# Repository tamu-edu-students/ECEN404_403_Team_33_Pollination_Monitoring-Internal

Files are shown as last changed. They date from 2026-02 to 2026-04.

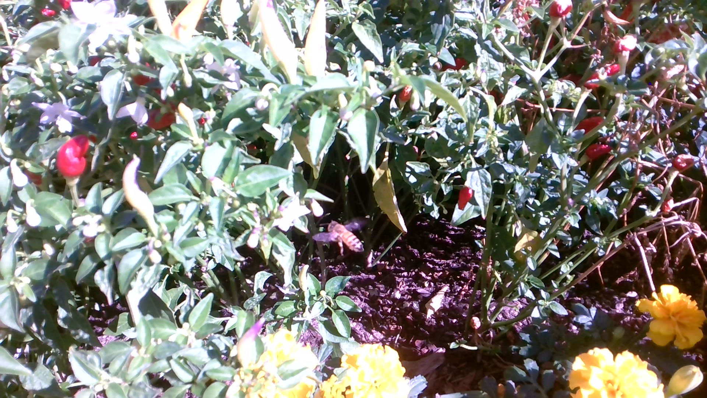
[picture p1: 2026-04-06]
pi_program/sample0.jpg

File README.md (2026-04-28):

# ECEN 404 / ECEN 403 — Team 33 Pollination Monitoring System (AgriPollinate)

## Overview

AgriPollinate is a smart pollination monitoring system designed to help farmers track pollinator activity in real time. Traditional monitoring methods are manual, slow, and not scalable. This system automates the process using LiDAR sensing, image-based machine learning, and live dashboard visualization.

The system detects when insects interact with flowers, classifies them as pollinators or non-pollinators, and displays results through a live dashboard with heatmap visualization.

---

## System Architecture

The system is composed of multiple integrated subsystems working together in an end-to-end pipeline from detection to visualization:

| Subsystem | Folder | Description |
|---|---|---|
| LiDAR Processing & ML | `lidar_ML/` | Motion detection, feature extraction, Random Forest classification |
| Image Classification | `image_ML/` | YOLOv8-based insect detection via FastAPI backend |
| Raspberry Pi Control | `pi_program/` | Hardware coordination and event pipeline triggering |
| LiDAR Client | `lidar_client_communication/` | LiDAR data streaming and event generation |
| Communication Layer | `communication_protocol.py` | Structured packet-based messaging between subsystems |
| Web Dashboard | `agripollinate_webpage/` | Real-time detection results and heatmap visualization |
| Power / Hardware | `board_v1_files/`, `board_v2_file/` | Custom PCB designs for solar power management |
| Enclosure | `enclosing_v1_stl/` | 3D-printed housing structure |

---

## Data Flow

```
LiDAR detects motion near flower
          ↓
Event generated with flower ID + timestamp
          ↓
Camera captures corresponding image
          ↓
Image ML model classifies insect (YOLOv8)
          ↓
LiDAR ML model validates classification (Random Forest)
          ↓
Sensor fusion merges both results
          ↓
Data sent to dashboard via TCP communication layer
          ↓
Heatmap updated in real time
```

---

## Key Features

- Real-time pollinator detection at the flower level
- LiDAR-based motion analysis with ML classification
- YOLOv8 image-based insect detection
- Random Forest LiDAR model with ~92% cross-validation F1 score
- Sensor fusion between camera and LiDAR subsystems
- TCP-based structured packet communication
- Live heatmap dashboard visualization
- Custom dataset collected from real hardware deployment
- Batch data collection pipeline for model retraining

---

## Machine Learning Components

### LiDAR Model (`lidar_ML/`)
- **Algorithm:** Random Forest classifier
- **Input:** Feature vectors extracted from LiDAR scan sequences
- **Output:** `pollinator` / `non-pollinator` + confidence score
- **Performance:** ~92% cross-validation F1 score

### Image Model (`image_ML/`)
- **Algorithm:** YOLOv8 object detection
- **Input:** Camera frames triggered by LiDAR events
- **Output:** Bounding box + insect class label
- **Backend:** FastAPI inference server

---

## Dataset

Both ML models use custom datasets collected from real hardware tests in the deployment environment:

- Bees
- Butterflies
- Ladybugs
- Beetles
- Grasshoppers
- Environmental noise / non-insect motion

LiDAR event data is stored in `lidar_ML/dataset/`. Image data is managed within `image_ML/`.

---

## Hardware

- Raspberry Pi 5
- LiDAR sensor module
- Camera module
- Custom PCB (v1 and v2 designs)
- Solar power management system
- 3D-printed enclosure housing

---

## Communication Protocol

All subsystems communicate using a structured packet format defined in [`communication_protocol.py`](communication_protocol.py). Key packet types include:

- `PACKET_ID_LIDAR_OUTGOING` — LiDAR event data from the sensor
- `PACKET_ID_IMAGE_RESPONSE` — Image classification result from the camera subsystem
- `PACKET_ID_LIDAR_RESPONSE` — LiDAR ML classification result

---

## Folder Structure

```
ECEN404_403_Team_33_Pollination_Monitoring-Internal/
│
├── lidar_ML/                      # LiDAR ML subsystem (see lidar_ML/README.md)
├── image_ML/                      # Image-based ML detection subsystem
├── lidar_client_communication/    # LiDAR data streaming client
├── pi_program/                    # Raspberry Pi hardware control
├── communication_protocol.py      # Shared packet communication layer
├── agripollinate_webpage/         # Web dashboard frontend
│
├── board_v1_files/                # PCB v1 design files
├── board_v2_file/                 # PCB v2 design files
├── enclosing_v1_stl/              # 3D enclosure STL files
│
├── 403_presentations/             # ECEN 403 presentation materials
├── presentations_404/             # ECEN 404 presentation materials
│
└── README.md                      # This file
```

---

## System Improvements (ECEN 403 → ECEN 404)

- Switched from rule-based scan logic to ML-based LiDAR classification
- Replaced cloud communication with TCP-based local system
- Improved dataset quality and removed duplicate/noisy samples
- Added sensor fusion between LiDAR and camera subsystems
- Improved real-time synchronization between subsystems
- Introduced structured packet communication protocol
- Built full end-to-end automated detection pipeline

---

## Results

- ~92% pollinator classification accuracy on held-out test set
- Reliable real-time detection pipeline with low latency
- Stable sensor fusion logic across LiDAR and camera
- Successful full system integration and deployment testing

---

## Future Improvements

- Add long-term database storage for historical activity tracking
- Improve model performance on edge cases and rare insect types
- Expand dataset with more environmental and lighting variations
- Optimize real-time inference speed for embedded deployment
- Improve dashboard analytics and user-facing reporting
- Deploy cloud backup system for data redundancy

---

## Team

ECEN 403 / ECEN 404 — Team 33
SICKSense PathFinder AgriPollinate
- [`Paavan Bagla`](https://github.com/PaavanBagla)
- [`Josiah Faircloth`](https://github.com/Josiahtate-tamu)
- [`Jason Agnew`](https://github.com/oops23)
- [`Samuel Ramos`](https://github.com/samwr-1)

Texas A&M University

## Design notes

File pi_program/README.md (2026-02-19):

# SICKSense Agripollinate Pi Program

This folder contains the Raspberry Pi master-side runtime for flower-visit event detection, image capture, and bidirectional packet routing between image and LiDAR clients.

## Updated Program Structure

The architecture has been refactored from the earlier object-tracking layout into an event-driven, flower-centric pipeline:

1. LiDAR stream is read in real time.
2. Flower occupancy is detected with per-flower thresholds and confirmation windows.
3. Event start triggers image burst capture/transmission.
4. Event end packages visit data for LiDAR data client transmission.
5. Master forwards response packets between image and LiDAR clients using a shared protocol.

## Files

### Core Runtime Modules

- **`master_main.py`**
     - Main orchestrator for all subsystems.
     - Handles startup/shutdown, watchdog checks, testing mode, event callbacks, and cross-server linking.

- **`lidar_parser.py`**
     - Manages TCP connection to the SICK LiDAR scanner.
     - Parses `LMDscandata` telegrams.
     - Supports selective index parsing so only required flower angle indices are decoded for detection.

- **`event_detector.py`**
     - Performs flower visit detection from scan data.
     - Uses configured flower angle indices + background distances.
     - Emits `start` and `end` events with distance history and metadata.

- **`image_capture.py`**
     - Runs image server socket and captures images via `fswebcam`.
     - Sends image data with packet headers (`1050`) and receives image-client responses (`2050`).
     - Forwards responses to the LiDAR data server when connected.

- **`lidar_data_server.py`**
     - Runs LiDAR data server socket for event payload delivery.
     - Sends event packets (`1025`) and handles LiDAR-client responses (`2025`).
     - Forwards responses to the image server when connected.

- **`communication_protocol.py`**
     - Defines packet header/payload format, serialization, and parsing.
     - Defines packet IDs used by both server paths (`1025`, `1050`, `2025`, `2050`).
     - Provides shared event ID helpers.

### Setup / Utility Module

- **`flower_setup.py`**
     - One-time/setup tool to build flower configuration from baseline scans.
     - Produces flower angle indices and background distances for use by the event detector.

### Data Directories

- **`image_downloads/`** - local image output/download area.
- **`lidar_downloads/`** - local LiDAR/event data output/download area.

## High-Level Data Flow

```text
LiDAR Scanner
          -> lidar_parser
          -> event_detector
                -> on start: image_capture (send 1050 packets)
                -> on end:   lidar_data_server (send 1025 packets)

Image client response (2050)
          -> image_capture
          -> forwarded to lidar_data_server / LiDAR client

LiDAR client response (2025)
          -> lidar_data_server
          -> forwarded to image_capture / Image client
```

## Key Configuration (master_main.py)

- **LiDAR Connection**: `LIDAR_HOST`, `LIDAR_PORT`
- **Image Server**: `IMAGE_SERVER_HOST`, `IMAGE_SERVER_PORT`, `IMAGE_SAVE_DIR`, `IMAGE_RESOLUTION`, `BURST_SIZE`
- **LiDAR Data Server**: `LIDAR_DATA_HOST`, `LIDAR_DATA_PORT`, `LIDAR_DATA_SAVE_DIR`
- **Event Detection**: `EVENT_DIST_THRESHOLD`, `EVENT_START_CONFIRM_SCANS`, `EVENT_END_CONFIRM_SCANS`
- **Reliability**: `WATCHDOG_TIMEOUT`, `CONNECTION_TIMEOUT`

## Running

On Raspberry Pi (master):

```bash
cd pi_program
python3 master_main.py
```

## Dependencies

Python standard library only for core runtime modules.

System dependency for image capture:

- `fswebcam` (example install on Debian/Raspberry Pi OS):

```bash
sudo apt-get install fswebcam
```

## Change Summary vs Previous Structure

- Replaced legacy object-tracking-centric flow with flower visit event detection.
- Added/standardized packet-based cross-client protocol support through `communication_protocol.py`.
- Added dedicated LiDAR data server path via `lidar_data_server.py`.
- Added setup utility `flower_setup.py` for deriving flower index/background configuration.
- Updated LiDAR parse path to support selective index decoding for lower per-scan processing load.

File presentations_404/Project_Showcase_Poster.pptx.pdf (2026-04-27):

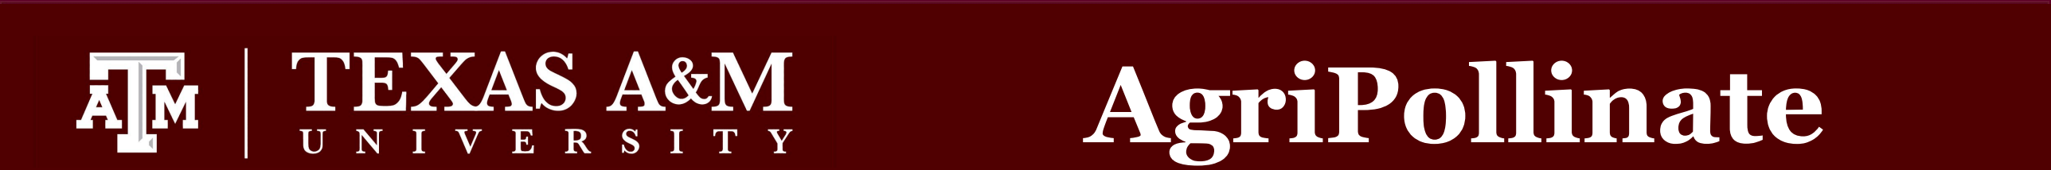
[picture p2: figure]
AgriPollinate

## Engineering Analysis

Throughout the course, our project changed in many ways, our scope, data collection methods, and power had to be refined to match our goals. System validation was performed across hardware and software subsystems. Detection accuracy was verified within a set detection range under field conditions. The ML classification models were trained and evaluated on labeled pollinator image datasets. Finally, the PCB power charging rate was validated with and without system load.

6cm

Problem Definition

Farmers lack an efficient and scalable way to monitor pollination, relying on manual and inconsistent methods.

AgriPollinate uses LiDAR and image based detection to automatically track and classify pollinator activity, displaying results through heatmaps on a dashboard.

The portable, solar powered system enables real time field deployment and improved decision making.

Methodology

- Setup: Flowers are configured with GPS coordinates in the system and dual TCP connections are established while the devices are powered by a PCB.
- Detection: The LiDAR continuously scans flowers for movement activity.
- Event Trigger: When movement is detected across 6 consecutive scans, an event is triggered and the camera captures an image of the flower.
- Classification: LiDAR data is sent to the ML model; camera image is sent for visual classification. Both are processed simultaneously.
- Dashboard: Displays LiDAR heatmap, insect species counts, top 3 pollinators, insect visits per each hour of the day, and triggers pest alerts.

## Outcomes

HERE PUT THE OUTCOMES, CONSOLE OUTPUT? GRAPHS AND CHARTS?

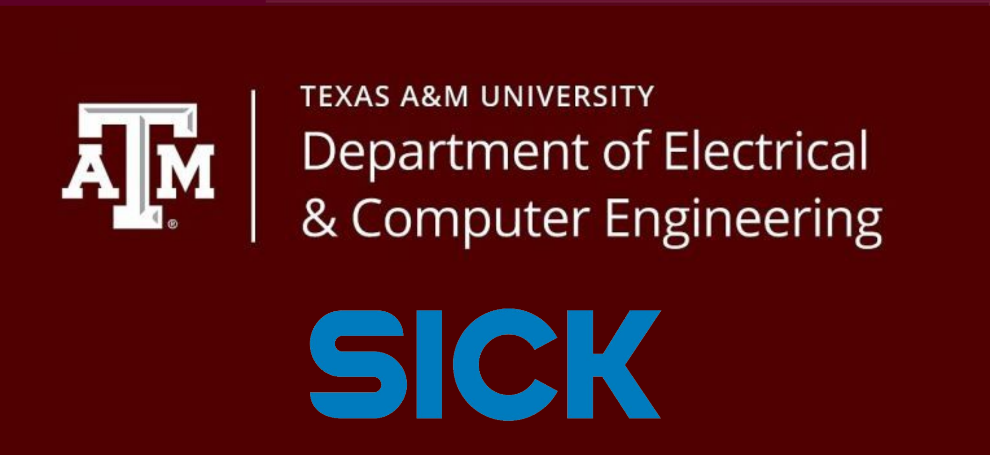
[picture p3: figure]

## Impact

Our project serves as a proof of concept model for a pollination monitoring system which can provide farmers with real-time pollination data to make faster, more informed decisions and reduce reliance on manual monitoring, cutting labor costs and human error. Heat-map visualization enables spatial analysis of pollinator hotspots across fields which can inform hive placement adjustments and solar-powered portability makes deployment viable for small and large-scale farms alike.

## References

- https://www.sciencedirect.com/science/article/pii/S2214574525000379 (https://www.sciencedirect.com/science/article/pii/S2214574525000379)

## Acknowledgments

The team would like to thank SICK for their generous sponsorship and providing the TiM551 LiDAR.

Special thanks to Faculty Advisor Prof. Stavros Kalafatis, Dr. John Lusher, and TA Roman Vengas for their guidance.

### Jason Agnew | Paavan Bagla | Josiah Faircloth | Samuel Ramos

Sponsor: SICK | Faculty: Stavros Kalafatis

Performance Metrics for Rasp. Pi

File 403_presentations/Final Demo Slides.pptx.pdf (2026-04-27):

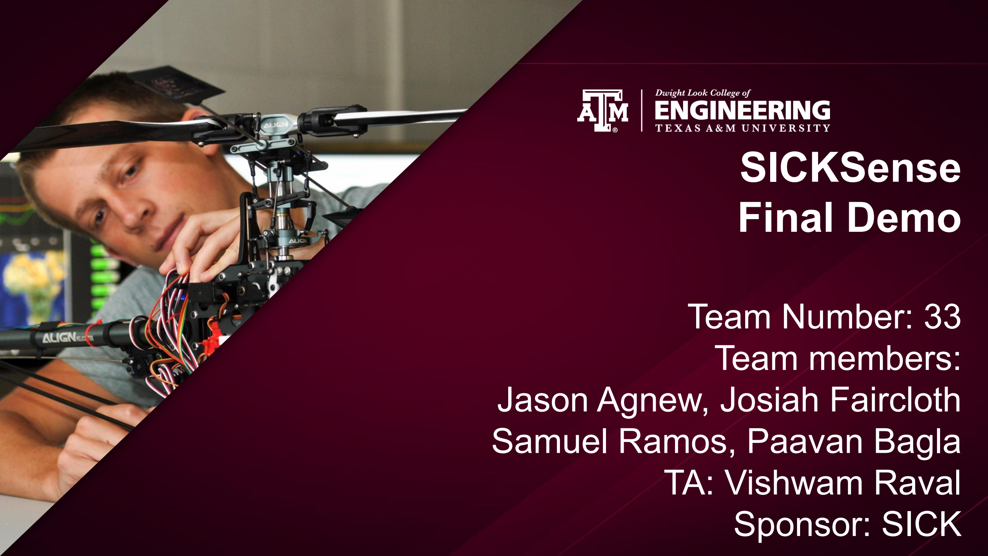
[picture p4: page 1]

# SICKSense Final Demo

## Team Number: 33 Team members: Jason Agnew, Josiah Faircloth Samuel Ramos, Paavan Bagla TA: Vishwam Raval Sponsor: SICK

# Project Summary

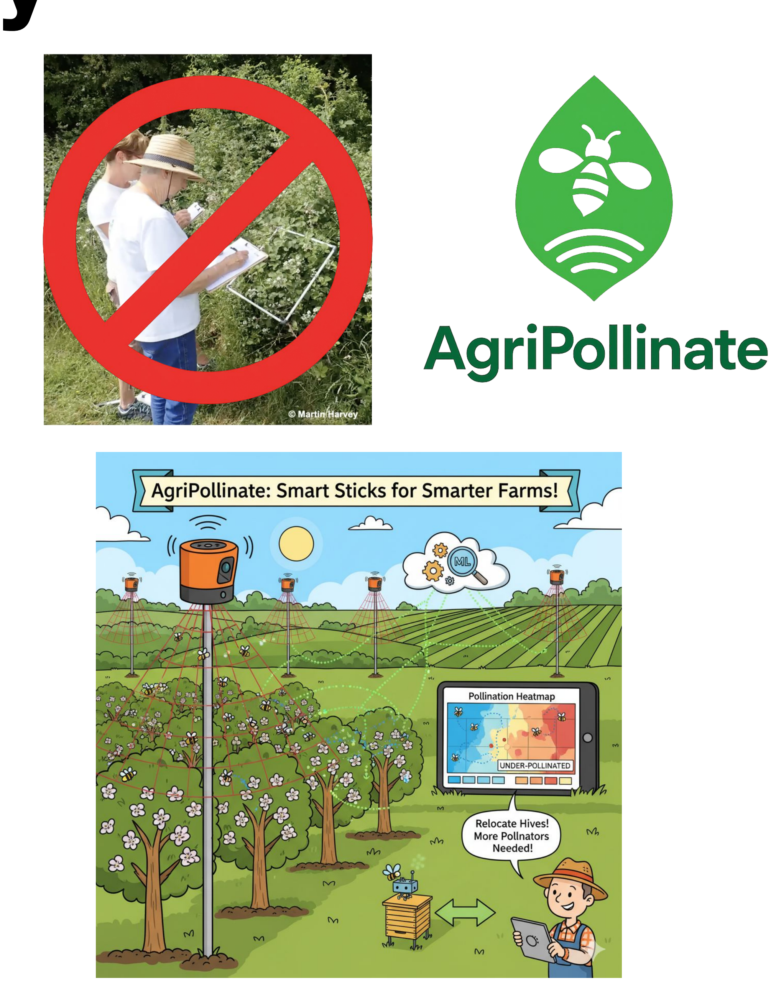
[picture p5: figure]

Problem statement:
- Farmers lack reliable, real-time insights into pollination activity. Existing methods are reactive, labor-intensive, and often inaccurate, leading to missed pollination deficits that directly reduce crop yield and quality.

Our Solution:
- AgriPollinate is a Light Detection and Ranging (LiDAR)-powered monitoring system that continuously tracks pollinator activity and generates easy-to-read heatmaps.
- Farmers can access these heatmaps through a simple dashboard, allowing them to quickly identify under-pollinated areas, optimize hive placement, and improve crop yield and quality.

# System Overview

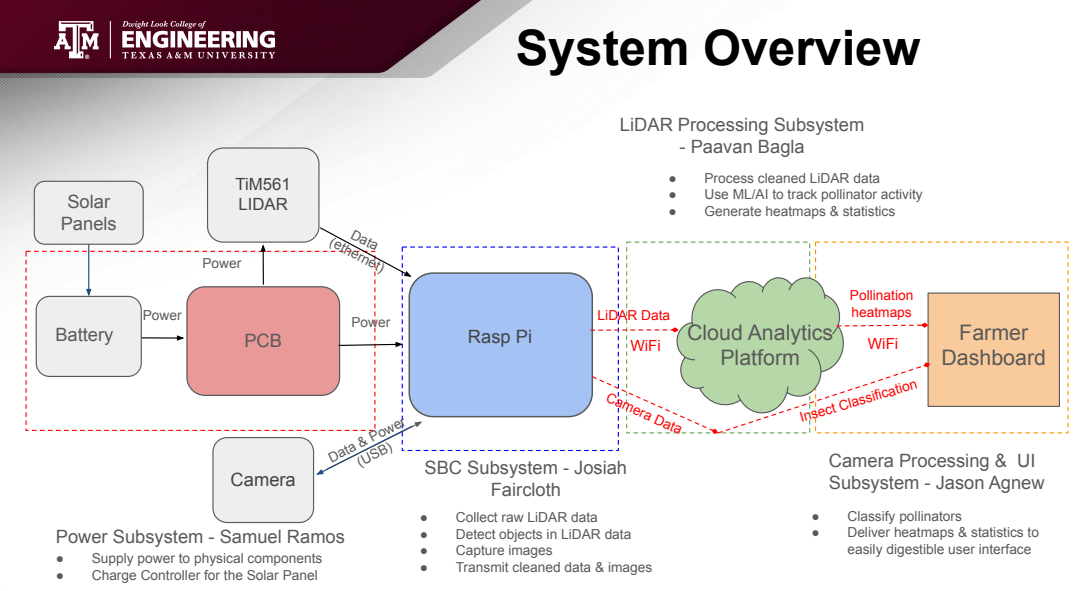
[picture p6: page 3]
Power; Data (ethernet); Pollination heatmaps; Insect Classification; PCB; TiM561 LIDAR; Rasp Pi; Camera; Cloud Analytics Platform; Farmer Dashboard; Battery; Data & Power; (USB); Faircloth; - Paavan Bagla; LiDAR Data; Camera Data; WiFi; Solar Panels

LiDAR Processing Subsystem

● Process cleaned LiDAR data
● Use ML/AI to track pollinator activity
● Generate heatmaps & statistics

Camera Processing & UI
Subsystem - Jason Agnew

SBC Subsystem - Josiah

● Collect raw LiDAR data
● Detect objects in LiDAR data
● Capture images
● Transmit cleaned data & images

● Classify pollinators
● Deliver heatmaps & statistics to
easily digestible user interface

Power Subsystem - Samuel Ramos
● Supply power to physical components
● Charge Controller for the Solar Panel

# Single Board Computer (SBC) Subsystem

Josiah Faircloth

Designed:
- Image capture & transmission program
– Captures images via camera attached to Raspberry Pi and transmits using TCP
- LiDAR data collection program
– Connects to TiM561 using TCP, receives scan data, and writes to a file
- LiDAR data object detection algorithm
– Reads scan data file, groups data points into objects, and triggers when a new object is detected
- Integrated program unifying all previous modules including a watchdog timer.

Tested:
- TCP/SSH connections with raspberry pi
- Image capture & transmission latency
- TiM561 connection & data parsing
- Object detection algorithm accuracy

# SBC Subsystem

Josiah Faircloth

Validation:
- >1 hr stable connection between pi and device on same network
- First Image ~1ms after trigger, average latency between pictures is ≤ 200ms
- >1 hr successful connection & data parsing with LiDAR
- Roughly 8/10 successful detection with simulated insect
- Roughly 3/10 detection triggers are false positives

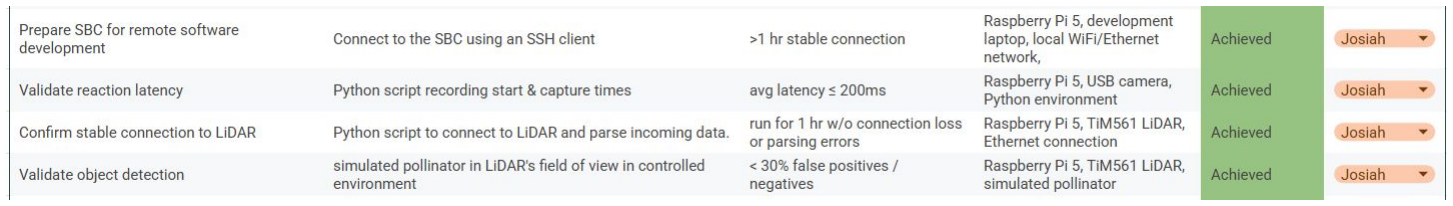
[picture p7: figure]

# SBC Subsystem

Josiah Faircloth

404 Tasks:
- Integrate TCP server/client with LiDAR & camera processing subsystems
- Optimize algorithm for performance and memory use to reduce strain on Raspberry Pi
- Continued testing and optimization of object detection algorithm
- Implement memory management system for pi
- Field testing over extended periods with real bees

## LiDAR Data Processing & Pollination Heatmaps System:

### Subsystem Summary — Paavan Bagla

Goal:
- Detect, identify, and visualize bee activity using LiDAR data to generate pollination heatmaps that inform autonomous robot behavior.

Design & Implementation:
- Integrated RViz + Gazebo simulation environment for sensor and visualization testing
- Built ROS2 pipeline for LiDAR /scan ingestion, bee point extraction, clustering, and heatmap generation
- Implemented both real-time and cumulative heatmap logic for visualizing bee activity

## LiDAR Data Processing & Pollination Heatmaps System:

### System Design (Algorithms Used) — Paavan Bagla

- Polar-to-Cartesian Conversion & Filtering: Transforms LiDAR (angle, range) pairs into 2D (x, y) coordinates and removes invalid or noisy readings.
- DBSCAN clustering: Uses density-based clustering to group nearby LiDAR points, helping distinguish actual bee detections from random noise.
- Gaussian smoothing: Applies Gaussian filtering using SciPy (or fallback) to smooth the heatmap grid and highlight consistent regions of bee activity.
- Heatmap accumulation logic: Updates two maps:
– | Real-time heatmap → live detections per frame
– | Cumulative heatmap → tracks total pollinating bee activity and count over time.
- ROS2 integration for real-time data streaming: Subscribes to /scan, processes detections, and publishes heatmaps to RViz.

## LiDAR Data Processing & Pollination Heatmaps System:

## Simulated LiDAR Detection in Gazebo & RViz

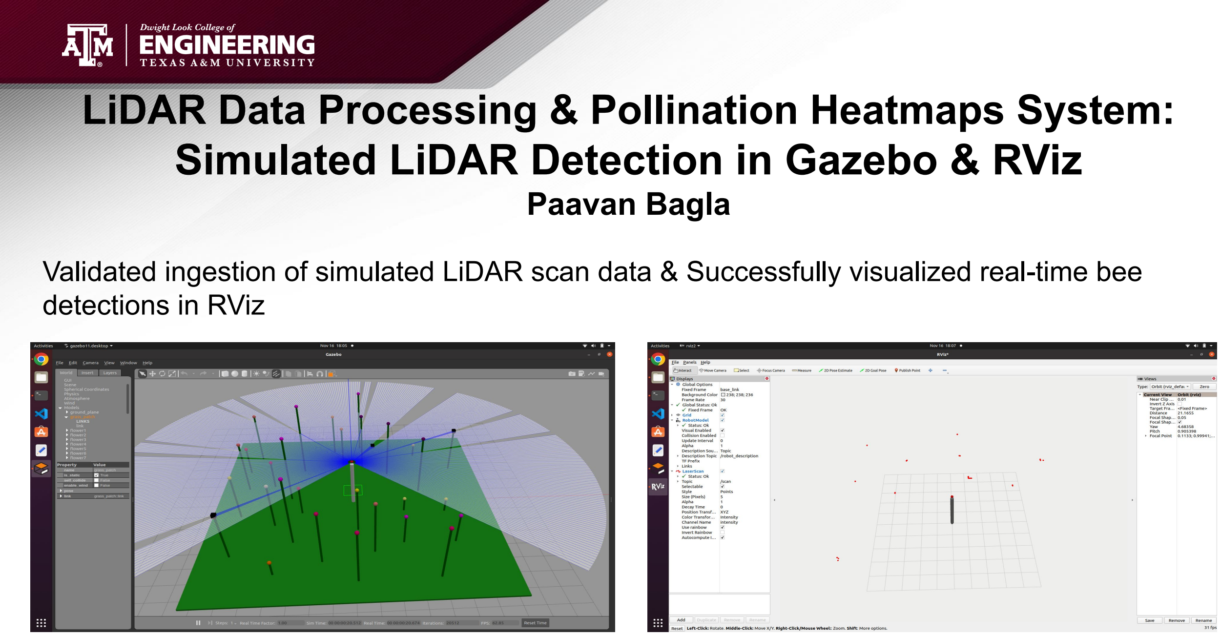
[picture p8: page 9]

### Paavan Bagla

Validated ingestion of simulated LiDAR scan data & Successfully visualized real-time bee detections in RViz

## LiDAR Data Processing & Pollination Heatmaps System:

### Validation Plan — Paavan Bagla

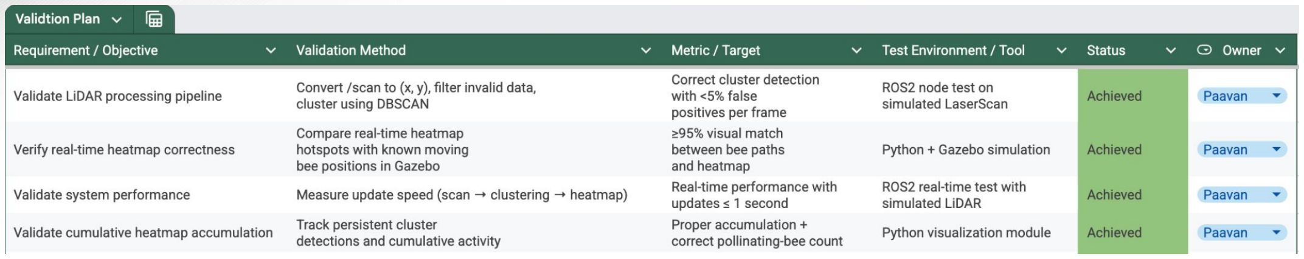
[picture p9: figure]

Testing & Validation:
- Verified LiDAR scan processing and visualization in RViz
- Tested with simulated bees in custom Gazebo environment
- Heatmaps reliably highlight real-time and cumulative pollination activity
- Counting + clustering algorithms run consistently in real time

## 404 Tasks: LiDAR & Heatmap Subsystem

### Paavan Bagla

- Machine Learning Integration
– Train a model to classify LiDAR points as bees vs. non-bees – Detect if a bee is pollinating
– Integrate ML predictions into the existing real-time pipeline
- Enhanced Heatmap Visualization
– Enhance real-time and cumulative heatmap visuals for better user experience
- Testing & Validation
– Test ML-enabled subsystem with larger simulated swarms
– Validate real-time performance with multiple moving bees
– Confirm correct pollinator counts and heatmap hotspot accuracy
- System Integration
– Use actual SICK TiM561 2D LiDAR data instead of simulated scans
– Integrate with other subsystems and finally display heatmaps and pollination analytics on the UI dashboard

# Camera Processing & UI Subsystem

Jason Agnew

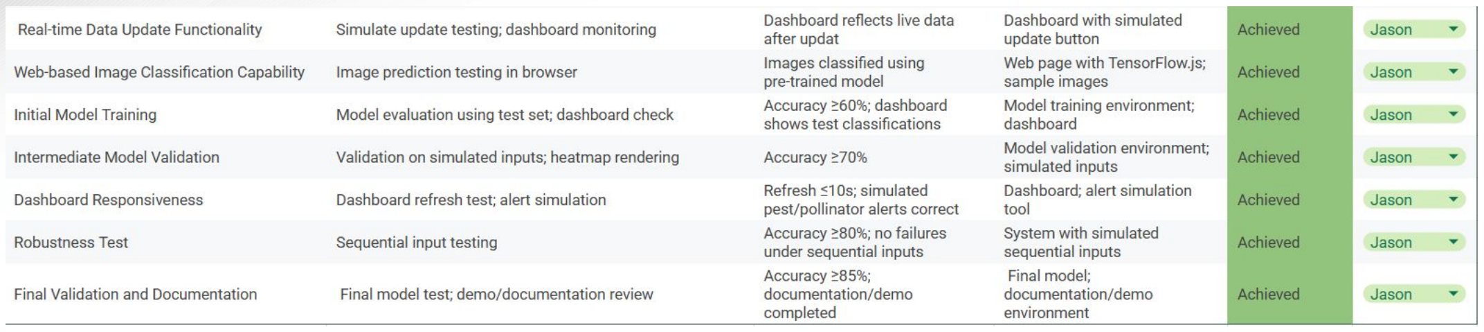
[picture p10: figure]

# Species

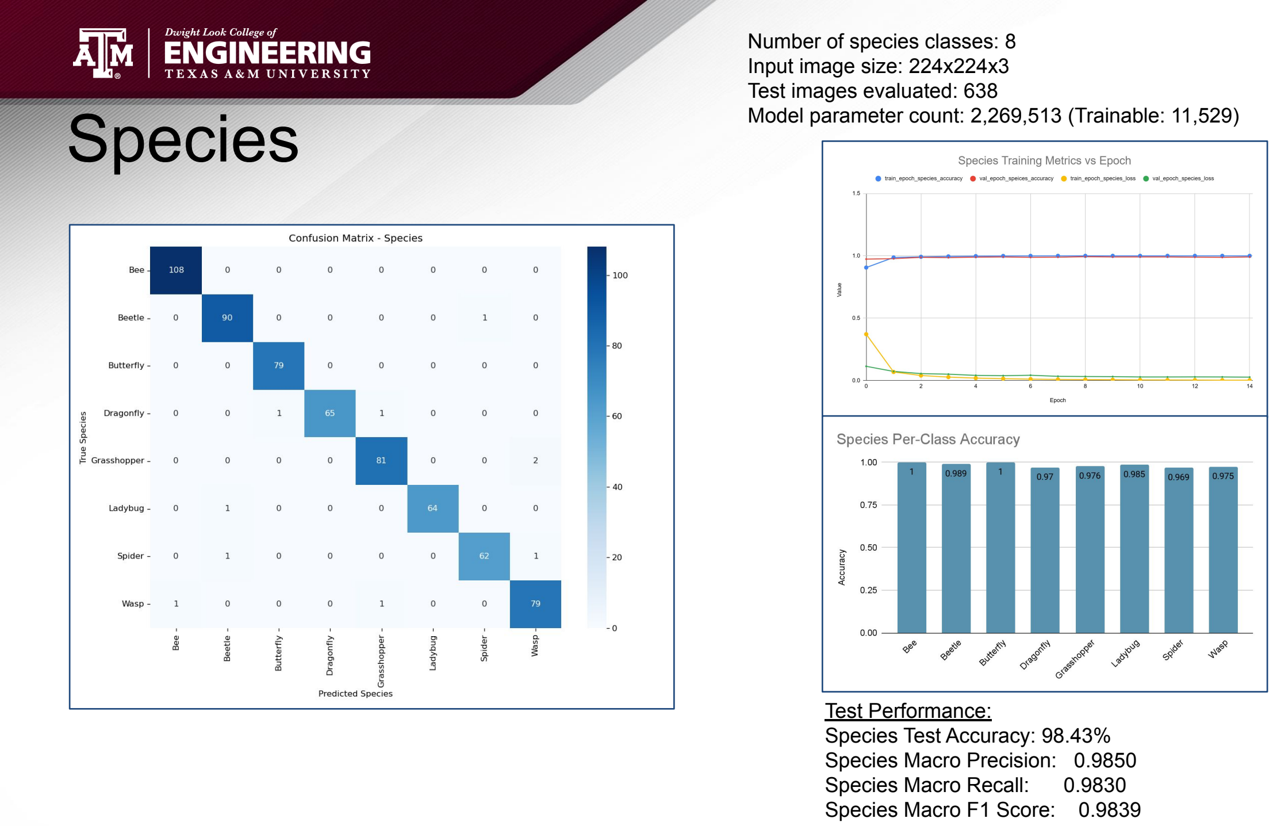
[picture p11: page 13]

Number of species classes: 8
Input image size: 224x224x3
Test images evaluated: 638
Model parameter count: 2,269,513 (Trainable: 11,529)

Test Performance:
Species Test Accuracy: 98.43% Species Macro Precision: 0.9850 Species Macro Recall: 0.9830 Species Macro F1 Score: 0.9839

Pollinator/Pest confusion matrix: [[316 3]
[ 8 311]]

# Roles

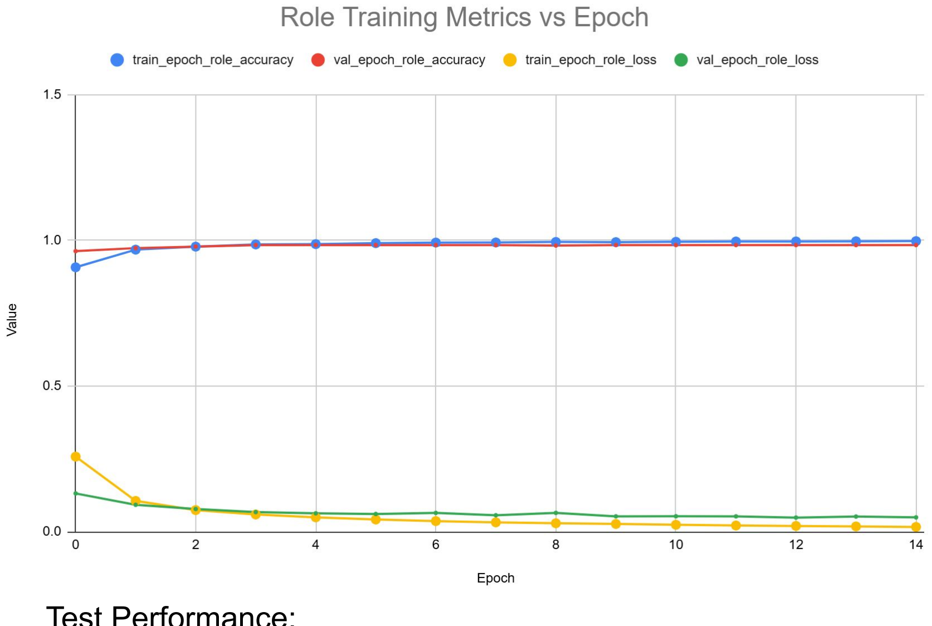
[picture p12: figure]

Test Performance:
Role Test Accuracy: 98.28% Role Precision: 0.9904
Role Recall: 0.9749
Role F1 Score: 0.9826

# Solar Power Management Circuit

### Samuel Ramos

403 Accomplishments Summary:
- Schematics for Step-down converter & Charge Controller has been design, passed the validation check and have been completed
- Learned a new software, Altium, in order to complete the schematics and more importantly the design of the PCB, which combines the two schematics
- PCB design has arrived and been validated to match the design in Altium

# Solar Power Management Circuit

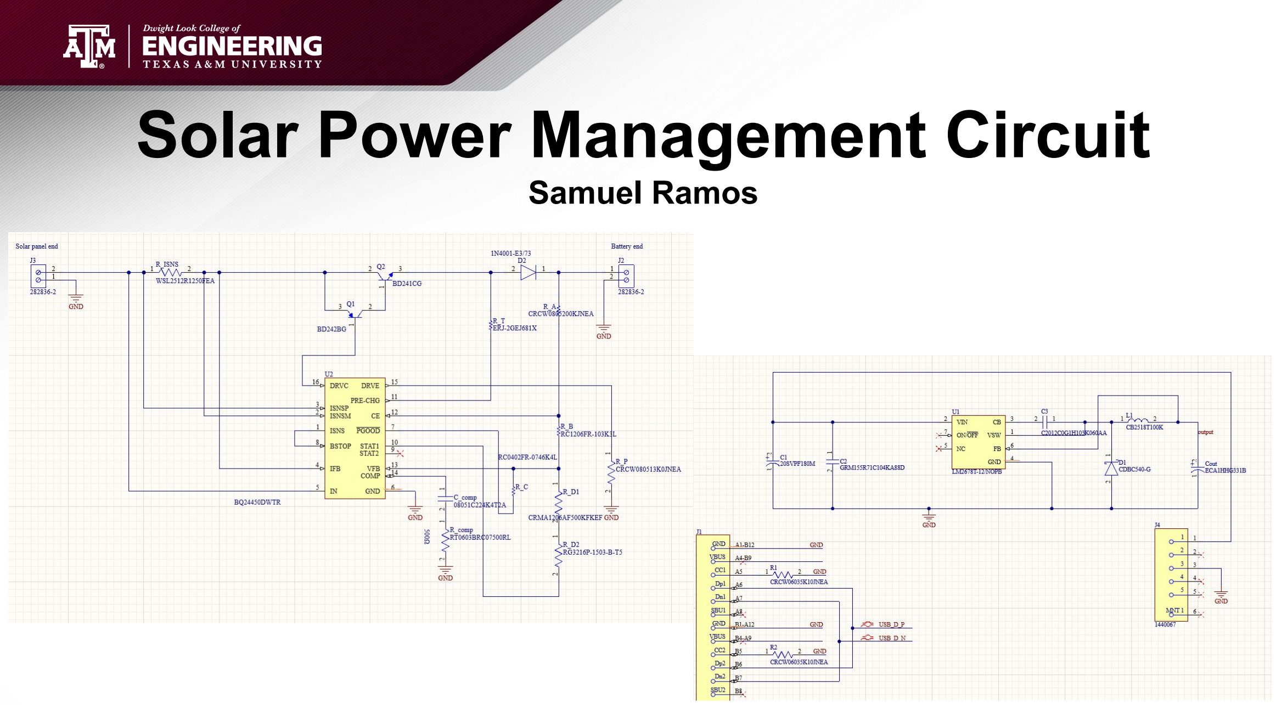
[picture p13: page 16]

### Samuel Ramos

# Solar Power Management Circuit

### Samuel Ramos

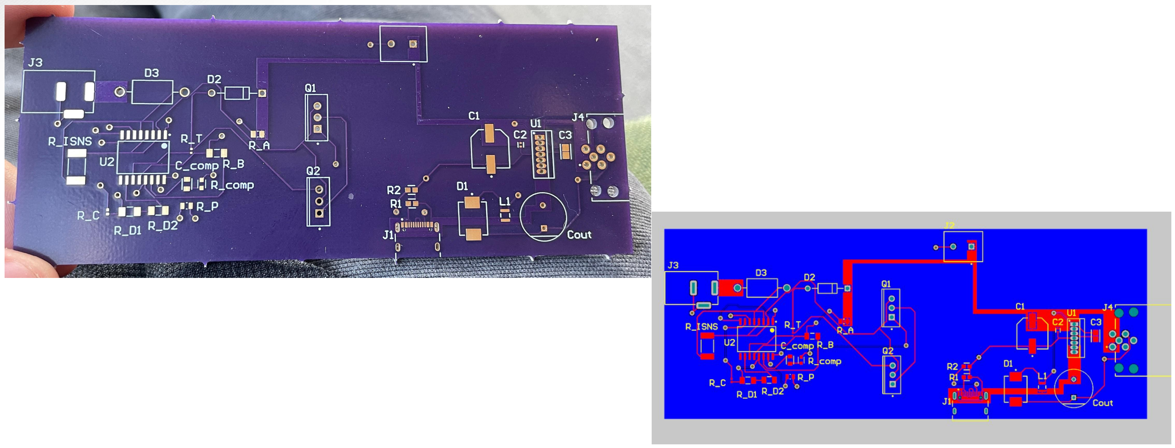
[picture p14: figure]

# Solar Power Management Circuit

### Samuel Ramos

Remaining Tasks:
- Soldering of parts onto PCB
- Testing of completed PCB (Power, I/O)
- Validation of testing compared to plan
Key Design activity to be completed in 404:
- Possible Redesign of Schematics and therefore PCB based on results of testing
- Enclose for PCB and components

## Remaining Tasks: Camera Processing & UI Subsystem

## Jason Agnew

Remaining Tasks Before Demo:
- Complete bounding-box annotations for the training dataset to finalize the labeled image set.
- Begin training the prebuilt MobileNet model using the fully annotated dataset.
- Evaluate model performance first using images from the dataset, then testing with images captured from the actual camera hardware.
- Test the end-to-end subsystem with multiple image bursts to validate dashboard refresh rate and real-time graph updates.

404 Tasks:
- Scale the model to support multi-insect detection and classification within a single image.
- Explore methods for integrating image-based classification results with LiDAR object-tracking to improve overall pollinator identification and reduce false counts.

## Thank you everyone for your attention! Feel free to ask any questions!

Team 33 - AgriPollinate

Team Members:
Jason Agnew
Josiah Faircloth
Samuel Ramos
Paavan Bagla

TA: Vishwam Raval
Sponsor: SICK

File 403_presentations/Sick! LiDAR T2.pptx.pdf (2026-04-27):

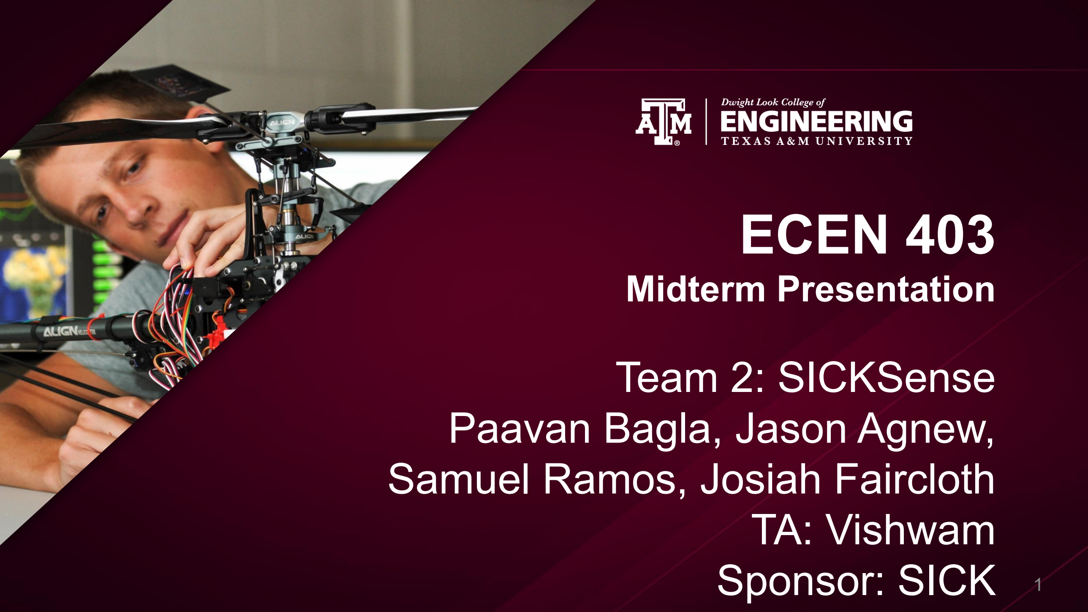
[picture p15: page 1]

# ECEN 403

# Midterm Presentation

# Team 2: SICKSense

Paavan Bagla, Jason Agnew,

# Samuel Ramos, Josiah Faircloth TA: Vishwam Sponsor: SICK 1

# Project Summary

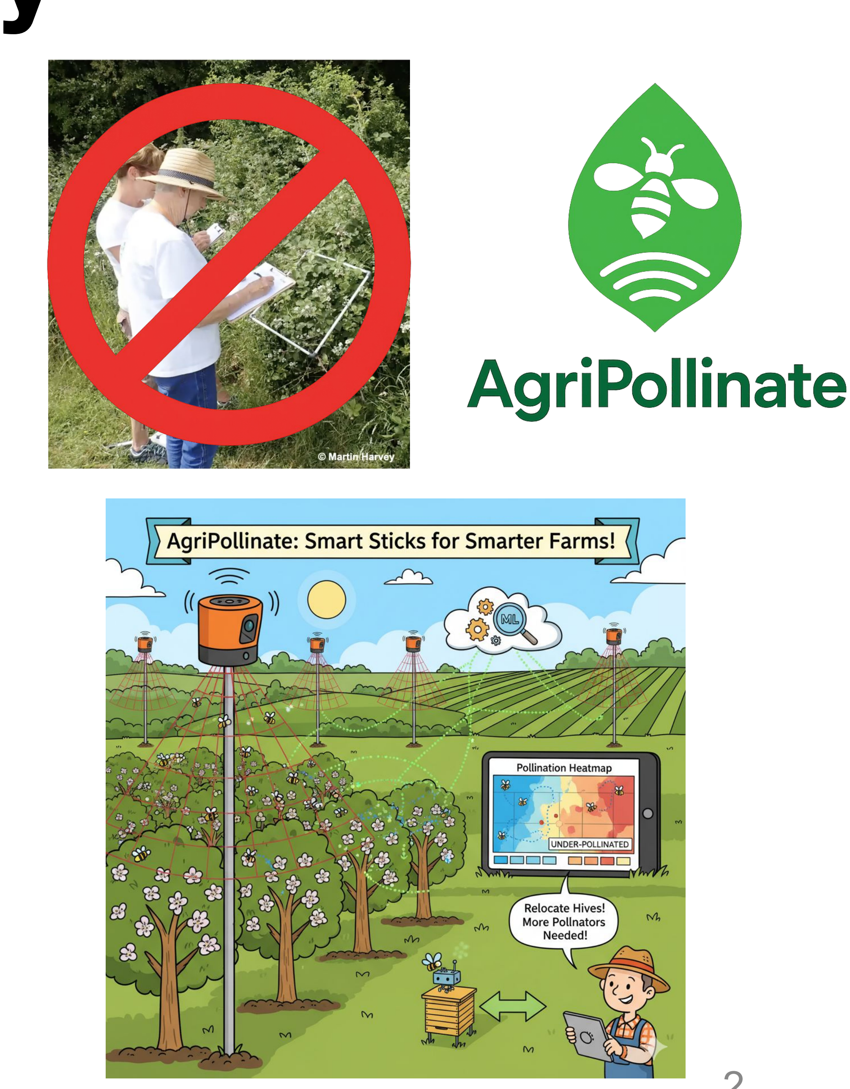
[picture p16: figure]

Problem statement: • | Farmers lack reliable, real-time insights into pollination
| activity. Existing methods are reactive, labor-intensive, and often inaccurate, leading to missed pollination deficits that directly reduce crop yield and quality.
Our Solution: • | AgriPollinate is a Light Detection and Ranging
| (LiDAR)-powered monitoring system that continuously tracks pollinator activity and generates easy-to-read heatmaps.

# - Farmers can access these heatmaps through a simple

| dashboard, allowing them to quickly identify under-pollinated areas, optimize hive placement, and improve crop yield and quality.

# System Overview

## LiDAR Processing Subsystem

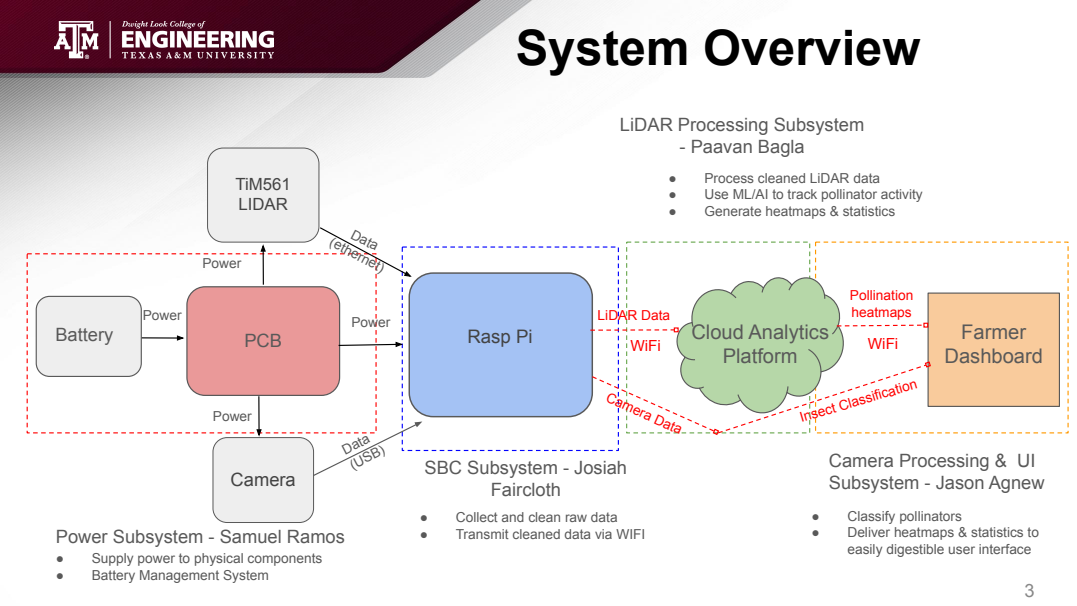
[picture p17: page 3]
Power; Data (ethernet); Pollination heatmaps; Insect Classification; PCB; TiM561 LIDAR; Rasp Pi; Camera; Cloud Analytics Platform; Farmer Dashboard; Battery; Data (USB); Faircloth; - Paavan Bagla; LiDAR Data; Camera Data; WiFi

● Process cleaned LiDAR data
● Use ML/AI to track pollinator activity
● Generate heatmaps & statistics

Camera Processing & UI
Subsystem - Jason Agnew

SBC Subsystem - Josiah

● Collect and clean raw data
● Transmit cleaned data via WIFI

● Classify pollinators
● Deliver heatmaps & statistics to
easily digestible user interface

Power Subsystem - Samuel Ramos
● Supply power to physical components
● Battery Management System

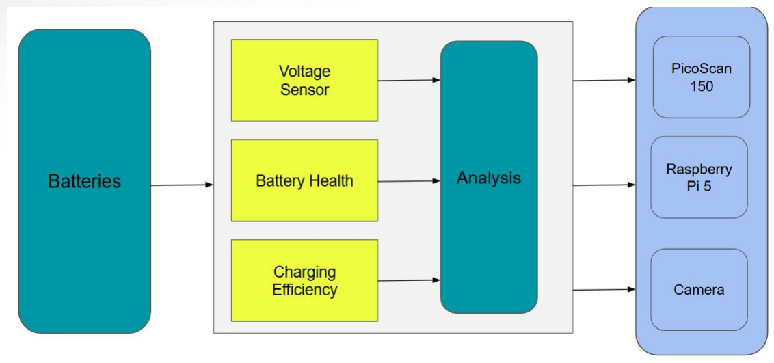
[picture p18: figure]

- This subsystem is responsible for the safety of a rechargeable battery, which it does by monitors the health and charge of the battery.
- The BMS will be designed and tested using Altium.
- Objective: The battery is to remain operational, and later on improve on its efficiency.
- Constraints: Battery budget.

# - Metrics: Charging Efficiency, Battery health, and Voltage range

- The BMS will connect the battery to the LiDAR, Camera, and Raspberry Pi.
- Powering each system while monitoring the battery.

# Battery Management System

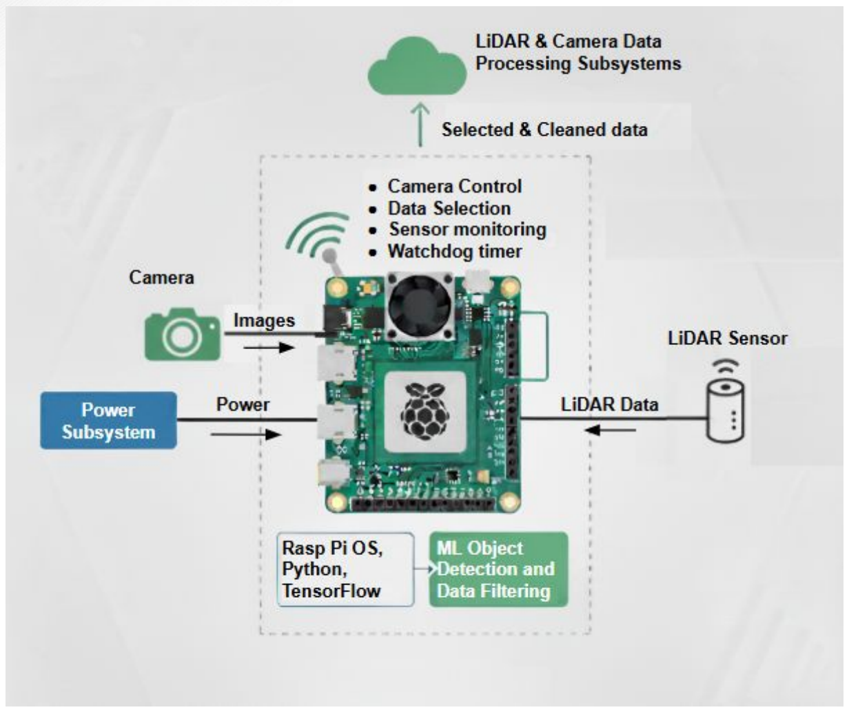
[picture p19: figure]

# Single Board Computer (SBC) Subsystem : Josiah Faircloth

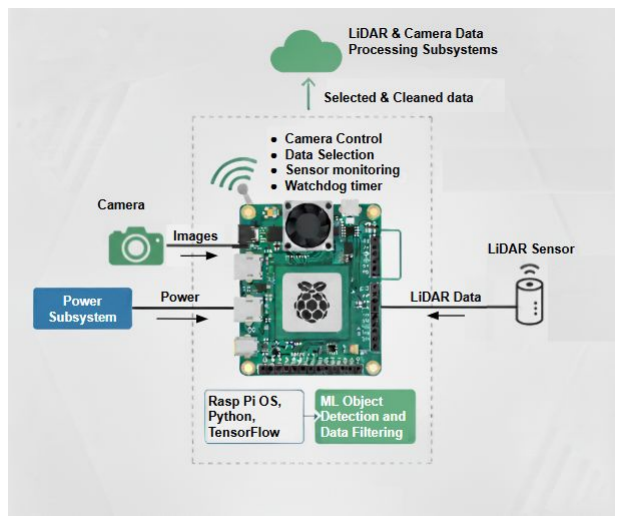
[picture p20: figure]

## - What does the subsystem do? – Collects and monitors data from LiDAR sensor and camera – Performs on-device machine learning for initial object detection and cleaning – Controls camera based on LiDAR Input

## - How is it being designed? – Tools: Python, TensorFlow Lite, SOPAS ET, Raspberry Pi OS – Key Parts: Raspberry Pi 5

## - Key objectives, constraints, metrics – Objectives: Reliably capture, process, and transmit data streams in real-time – Constraints: Power consumption, Thermal management (heatsink or fan) – Metrics: Inference Speed, Data Reduction

## - Interact with other subsystems

– Input: Direct connection to PicoScan150 (ethernet) and camera (USB), Powered by BMS (5V/5A USB-C)

## – Output: Transmits filtered LiDAR and camera data to cloud platform over WiFi

# SBC System : Josiah Faircloth

# SBC Subsystem : Josiah Faircloth

Criteria | Python on Raspberry Pi | C++ / Arduino on ESP32
Capability | Full OS allows for complex software, multitasking, AI/ML | Bare metal. Limited heavy computation or multitasking
Development | Python has simple syntax and vast libraries | C++ can be complex. Fewer high-level libraries
Performance | Powerful hardware | C++ is efficient, but hardware is a limiting factor
Power Consumption | Requires a robust power solution | Can run for long periods on a small battery.

# LiDAR Data Processing & Pollination Heatmaps System: Paavan Bagla

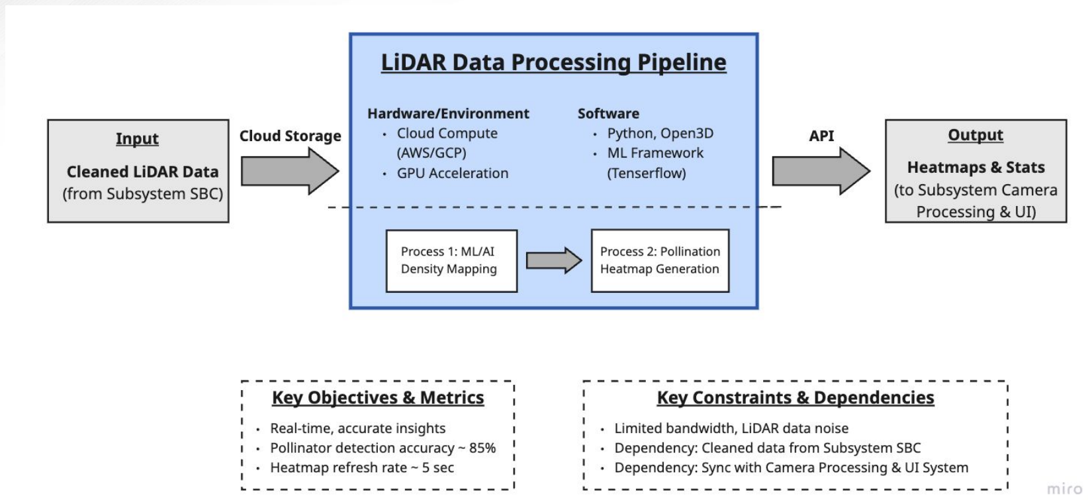
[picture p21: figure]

## - What does the subsystem do?

– Processes cleaned LiDAR data from cloud storage.
– Uses Machine Learning (ML) / Artificial Intelligence (AI) models to detect pollinator flight activity.
– Generates real-time heatmaps & statistics showing pollinator density and under/over-pollinated zones.

## - How is it being designed?

– Tools: Python, TensorFlow, Open3D for point cloud processing.
– Pipeline: LiDAR → Data cleaning (Subsystem SBC) → ML/AI density mapping → Dashboard visuals.
– Key Parts: Cloud compute (Amazon Web Services (AWS) / Google Cloud Platform (GCP)), GPU acceleration.

## - Key objectives, constraints, metrics?

– Objectives: Real-time, accurate pollination insights.
– Constraints: Limited bandwidth, noise in LiDAR data, power limits.
– Metrics: Pollinator detection accuracy ≥ 85%, heatmap refresh rate ≤ 5 sec.

# LiDAR Data Processing & Pollination Heatmaps System: Paavan Bagla

## - How will it connect to and interact with other subsystems?

– Input: Cleaned LiDAR data from Subsystem SBC.
– Output: Heatmaps & pollination density stats → Subsystem Camera Processing & UI System.
– Dependency: Must sync with Camera-based classification for validation.
Option | Pros | Cons | Decision
TensorFlow | Stable, good deployment tools | Slightly heavier | Selected
PyTorch | Easier experimentation | Less optimized for deployment | Not Selected
Python | Rich libraries for ML and point cloud processing, strong community support | Slower runtime than C++ for heavy computation | Selected

# LiDAR Data Processing & Pollination Heatmaps System : Paavan Bagla

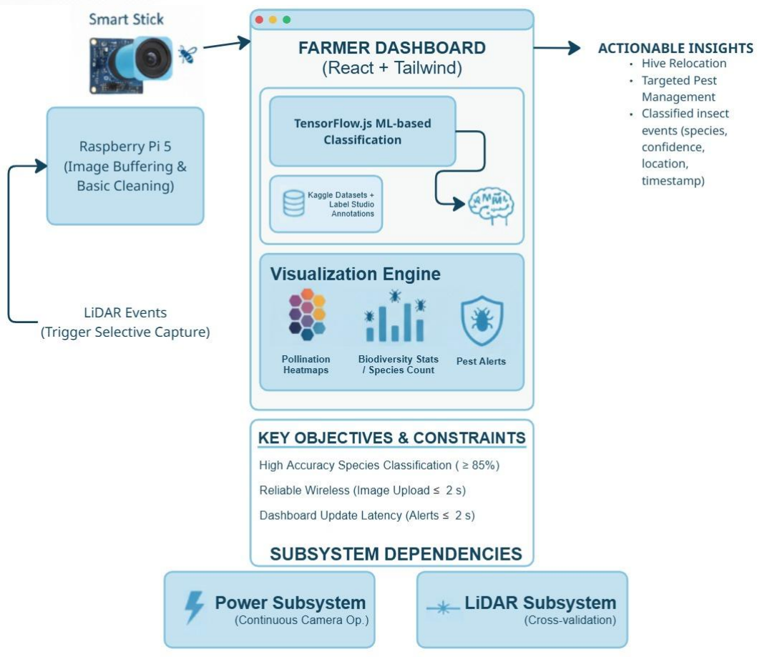
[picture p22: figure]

# Camera Processing & UI Subsystem: Jason Agnew

## - What does the subsystem do?

– Captures insect images near smart sticks via camera modules.
– Performs ML-based classification directly in the farmer dashboard using TensorFlow.js. – Dashboard visualizes results: pollination heatmaps, species count, pest alerts.
– Provides farmers with actionable insights (hive relocation, pest management).

## - How is it being designed?

– Tools: Kaggle datasets, Label Studio for annotation, Tensorflow.js for in-browser ML, React + TypeScript + Tailwind for UI, Figma for design.
– Pipeline: Camera → Rasp Pi 5 (buffer + basic cleaning) → Dashboard (classification + visualization)

## – Key Parts: Pi HQ Camera, Raspberry Pi 5 or similar for image forwarding

## - Key objectives, constraints, metrics?

– Objectives: High-accuracy species classification for pollinators vs pests, seamless real-time farmer dashboard with intuitive visuals.
– Constraints: Requires reliable wireless connection, bandwidth management (large image/video files), Latency must be low enough for “real-time” alerts.
– Metrics: Classification accuracy ≥ 85%, image upload latency ≤ 2 sec, dashboard update latency ≤ 10 sec.

# Camera Processing & UI Subsystem: Jason Agnew

# Camera Processing & UI Subsystem: Jason Agnew

## - How will it connect to and interact with other subsystems? – Inputs: - Camera images from SBC - LiDAR events to trigger selective image capture – Outputs: - Classified insect events (species, confidence, location, timestamp)

- Dashboard visualizations: pollination heatmaps, biodiversity stats, pest alerts.

## – Dependency:

- Relies on power subsystem for continuous camera operation.
- Integrates with LiDAR subsystem for cross-validation of pollinator activity.
Criteria | TensorFlow.js | TensorFlow on Cloud
Capability | Runs directly in browser. | Full TensorFlow stack.
Development | Easy integration with web apps. JavaScript ecosystem. | Integrates with enterprise ML pipelines, APIs, and cloud storage. Python ecosystem.
Performance | Limited by client hardware (CPU/GPU in browser). | Access to powerful GPUs.
Scalability | Each user runs locally, no central | Can scale to millions of users via
| server load. | APIs

# Project Execution & Validation

| 9/30 | 10/07 | 10/21 | 10/28 | 11/11 | 11/25 | 12/02
BMS (Samuel Ramos) | Familiarize myself with Altium, began working on PCB design. | Continue working on PCB, began preliminary testing | Finished PCB Design and already have it submitted to be made. | Develop testing plans for the BMS & see if any improvements can be made. | Receive PCB and begin hardware testing. | Full systems test and make revision notes. | Prepare report on BMS status and proposed improvements.

SBC Subsystem
(Josiah Faircloth)

Research &
Finalize SBC
choice, Install
needed libraries
and development
environments.

Procure SBC,
LiDAR, camera,
Install OS and
establish remote
access.
Validation: SBC is
booting and
accessible for
remote
development via
SSH.

Interface camera
module with SBC,
Develop script to
capture images,
Establish data
pipeline to cloud.
Validation: Camera
captures an image
within 200ms of a
“detection”.

Interface LiDAR by
configuring IPs,
Develop script to
parse data stream.
Validation: Script
connects to LiDAR,
captures data
stream, parses 5
mins of point cloud
data.

Develop software to
filter raw LiDAR
data, Implement ML
model to distinguish
potential insects
from noise.
Validation: System
can process
continuous LiDAR
stream and output
coordinates for a
simulated "object"
with <5% false
pos/neg

Integrate LiDAR
processing, camera
capture, and cloud
transmission,
Implement
watchdog timer.
Validation:
Operates for 12
hours w/o
intervention,
triggers camera on
LiDAR detections,
transmits data.
Watchdog timer is
functional

Optimize code for
efficiency, Prepare
live demo of full
functionality.
Validation:
Operates with
>98% data
transmission
success rate and
correctly triggers
the camera for
>90% of simulated
targets

# Project Execution & Validation

| 9/30 | 10/07 | 10/21 | 10/28 | 11/11 | 11/25 | 12/02
LiDAR Data Processing (Paavan Bagla) | Literature review on LiDAR applications in pollinator monitoring. Identified at least 3 LiDAR datasets for evaluation. | Select dataset (based on quality & resolution); Initial preprocessing scripts written (Python) for formatting LiDAR point clouds. | ML environment set up (Python + TensorFlow). Baseline model pipeline implemented and able to accept cleaned LiDAR data. | First round of model training completed. Generate and visualize initial density maps from small dataset subset. | Model refinement, incorporate filtering for noise reduction. Accuracy tested against validation subset; document metrics. | Generate refined pollination density heatmaps from dataset. Document preliminary results and limitations (accuracy, clarity of heatmaps). | Deliver semester prototype: dataset-driven pollination heatmap (proof-of-concept). Summarize dataset quality, model performance, and integration plan.

Camera
Processing & UI
Subsystem
(Jason Agnew)

Finalize
subsystem scope,
set up repos for
the dashboard and
ML, and secure
insect datasets.
Validation:
repository
initialized and at
least one dataset
successfully
loaded for
inspection.

Complete initial
Figma designs for
the farmer
dashboard and
begin data
annotation in Label
Studio. Validation:
mockups are
ready for review
and at least 200
images are
labeled.

Train a baseline ML
classifier, export it
for TensorFlow.js,
and create a
dashboard
component to
display
classification results
with mocked data.
Validation: model
reaches ≥60%
accuracy and
dashboard displays
test classifications.

Refine the ML
model with more
training and
preprocessing, and
add visualization
features like
heatmaps and
species counts.
Validation: model
achieves ≥70%
accuracy and
heatmaps render
correctly with
simulated inputs.

Simulate the image
pipeline (as if from
Raspberry Pi) and
test dashboard
latency for real-time
updates.
Validation:
dashboard
refreshes within
≤10 sec and
simulated
pest/pollinator
alerts appear
correctly.

Integrate simulated
LiDAR triggers for
cross-validation and
stress test the
system with
multiple events.
Validation:
classification
accuracy reaches
≥80% and the
system handles
sequential inputs
without failure.

Deliver a full
subsystem demo
showing dataset →
classification →
visualization →
alerts, and
document setup for
next year’s real Pi
integration.
Validation:
classification
accuracy reaches
≥85% and final
documentation/dem
o are completed.

# Questions?

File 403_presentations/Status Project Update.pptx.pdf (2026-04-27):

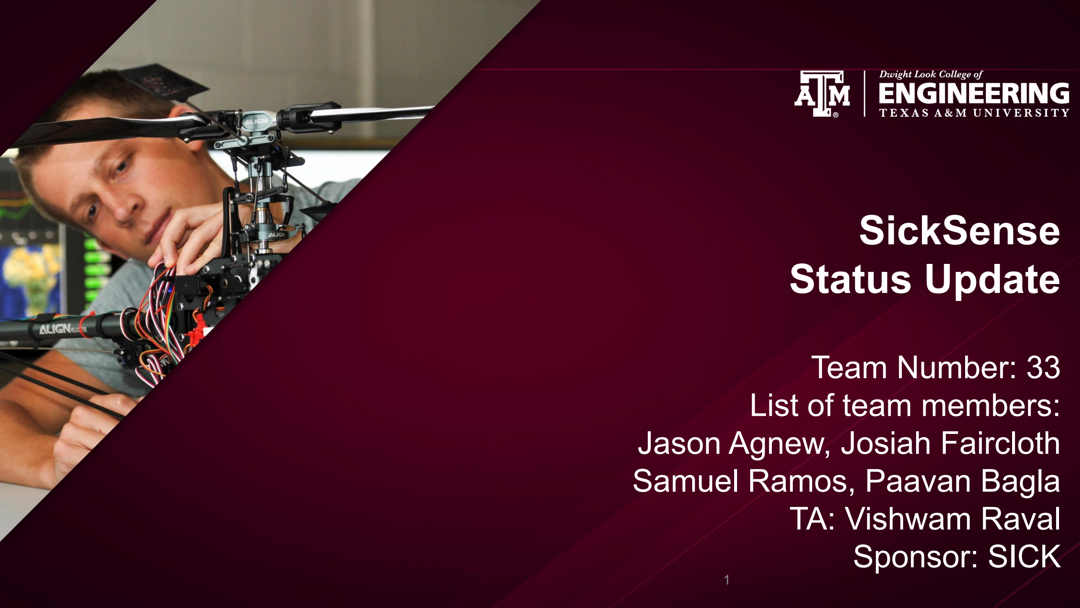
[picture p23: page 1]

# SickSense Status Update

## Team Number: 33 List of team members: Jason Agnew, Josiah Faircloth Samuel Ramos, Paavan Bagla TA: Vishwam Raval Sponsor: SICK

# Project Summary

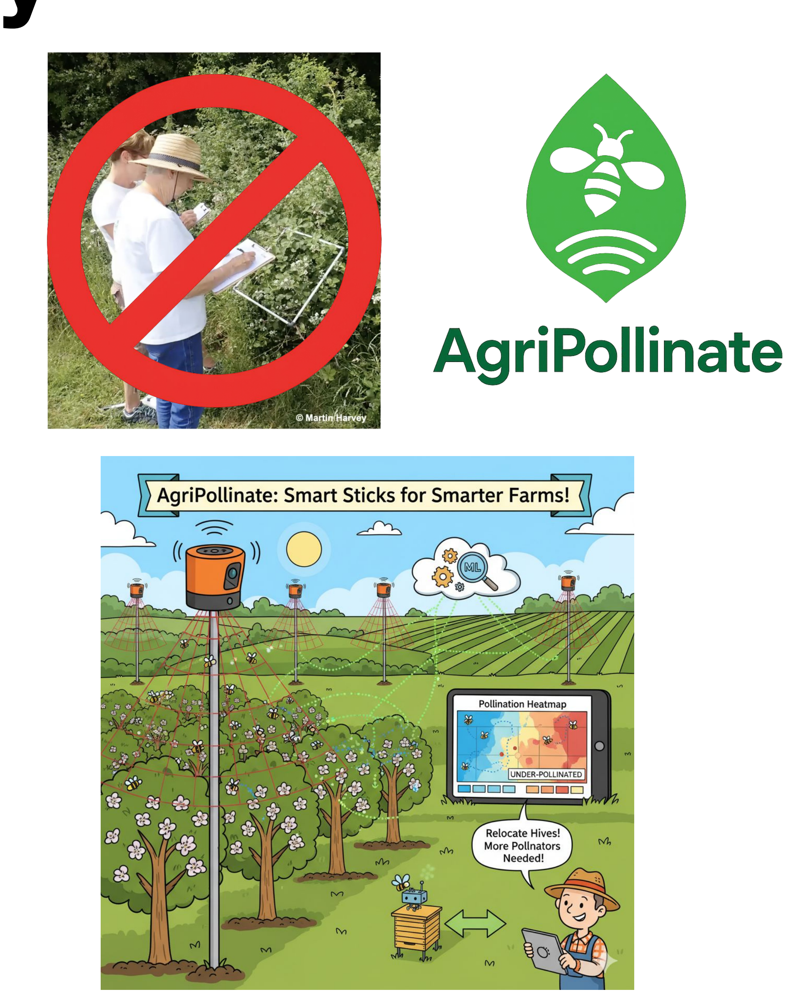
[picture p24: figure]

## Problem statement:

- Farmers lack reliable, real-time insights into pollination activity. Existing methods are reactive, labor-intensive, and often inaccurate, leading to missed pollination deficits that directly reduce crop yield and quality.

## Our Solution:

- AgriPollinate is a Light Detection and Ranging (LiDAR)-powered monitoring system that continuously tracks pollinator activity and generates easy-to-read heatmaps.
- Farmers can access these heatmaps through a simple dashboard, allowing them to quickly identify under-pollinated areas, optimize hive placement, and improve crop yield and quality.

# System Overview

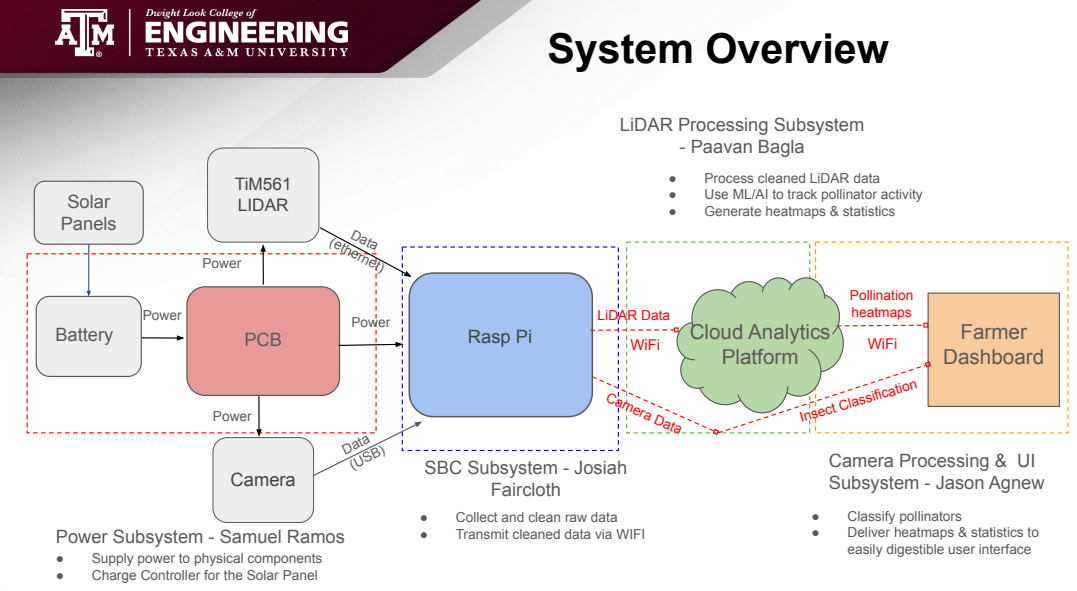
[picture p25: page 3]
Power; Data (ethernet); Pollination heatmaps; Insect Classification; PCB; TiM561 LIDAR; Rasp Pi; Camera; Cloud Analytics Platform; Farmer Dashboard; Battery; Data (USB); Faircloth; - Paavan Bagla; LiDAR Data; Camera Data; WiFi; Solar Panels

LiDAR Processing Subsystem

● Process cleaned LiDAR data
● Use ML/AI to track pollinator activity
● Generate heatmaps & statistics

Camera Processing & UI
Subsystem - Jason Agnew

SBC Subsystem - Josiah

● Collect and clean raw data
● Transmit cleaned data via WIFI

● Classify pollinators
● Deliver heatmaps & statistics to
easily digestible user interface

Power Subsystem - Samuel Ramos
● Supply power to physical components
● Charge Controller for the Solar Panel

Accomplishments since midterm update ~20 hrs of effort

Ongoing progress/problems and plans until the next presentation

- Completed schematic of the Charge controller
- Completed schematic of step-down converter
- Finish PCB Design
- Routing/Spacing
- Testing

Designed: The schematic and PCB for the Charge Controller & Step-down converter. Built: The schematic in Altium for said components, currently building the PCB Tested: The schematic in Altium, where it passed the Validation check

# Solar Power Management Circuit

Samuel Ramos

# Charge Controller


Next few slides for each subsystem | 5

Samuel Ramos

# Buck Converter


Samuel Ramos

Accomplishments since midterm update 24 hrs of effort

Ongoing progress/problems and plans until the next presentation

- Acquired SBC, LiDAR, and camera, Installed OS and established remote access.
- Interfaced camera module with SBC, Developed a script to capture image bursts on trigger, and transmit via Transmission Control Protocol (TCP).
- Currently Interfacing LiDAR, developing script to parse data stream.
- Will Develop software to filter raw LiDAR data, detect potential objects, and transmit data via TCP
- Will Integrate LiDAR processing, camera capture, and TCP

# Single Board Computer (SBC) Subsystem

Josiah Faircloth

# SBC Subsystem

Josiah Faircloth


Designed: Python server & client scripts for TCP, Python Script for image capture

Built: SBC, camera module, SSH connection

Tested: SSH connection, development environment, Image capture latency

Accomplishments since midterm update 30 hrs of effort

Ongoing progress/problems and plans until the next presentation

- Developed a LiDAR-camera simulation and calibration system that converts simulated bee detections from LiDAR coordinates into 2D image frame coordinates, then verified calibration accuracy (~85%) by re-projecting back to LiDAR space.
- Built a Gazebo-based farm simulation with a vertical pole and mounted LiDAR sensor to replicate realistic scanning and bee detection environments.
- Refine calibration parameters to increase projection accuracy beyond 90% and improve noise filtering in LiDAR detections.
- Develop and test the full pipeline (simulation → processing → heatmap) using both simulated and real LiDAR data to evaluate pollination density accuracy

### LiDAR Data Processing & Pollination Heatmaps System

Paavan Bagla

### LiDAR-Camera Simulation and Calibration


Paavan Bagla

### Gazebo-based farm simulation


Paavan Bagla

Designed: Coordinate transformation and farm simulation environment for LiDAR-camera calibration and bee trajectory modeling.

Built: ROS2-based LiDAR processing pipeline with simulation plugins and real-time data projection module.

Tested: Achieved ~85% calibration accuracy and validated realistic LiDAR returns from moving bee simulations.

Accomplishments since midterm update 25 hrs of effort

Ongoing progress/problems and plans until the next presentation

- Designed and implemented a farmer dashboard layout with an intuitive user interface.
- Enabled real-time data updates in the dashboard through a simulated update button, allowing users to experience live changes.
- Developed a basic web page featuring image classification capabilities, leveraging a pre-trained MobileNet model with TensorFlow.js for in-browser predictions.
- Enable photo transmission from the Raspberry Pi by converting TCP protocol data to an HTTP-compatible backend, allowing seamless integration with the farmer dashboard.
- Build a custom image classification model using annotated dataset, based on MobileNet architecture, to improve accuracy and support both species identification and pollinator/pest classification.
- Integrate the image selection and insect classification workflow from the basic web page into the dashboard, enabling users to select an image, classify the bee or other insect, and automatically update the dashboard charts with the new data.

# Camera Processing & UI Subsystem

Jason Agnew

# Camera Processing & UI Subsystem


Jason Agnew

Designed: Designed a farmer dashboard interface and image classification web page.
Built: Built the dashboard with real-time data updates and implemented web-based image classification using TensorFlow.js. Tested: Tested dashboard data updates and verified image classification predictions in the web page.

# Execution plan


# Validation plan


## Team 33 - AgriPollinate

## Team Members: - Jason Agnew - Josiah Faircloth - Samuel Ramos - Paavan Bagla

## TA: Vishwam Raval Sponsor: SICK

## Thank you everyone for your attention! Feel free to ask any questions!

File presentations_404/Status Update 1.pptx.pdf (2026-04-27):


# Team 33: SickSense Pathfinder Bi-Weekly Update 1

## Jason Agnew, Josiah Faircloth Samuel Ramos, Paavan Bagla

### Sponsor: SICK TA: Roman Venegas


# Project Summary

Problem Statement:
- Farmers lack reliable, real-time insights into pollination activity. Existing methods are reactive, labor-intensive, and often inaccurate, leading to missed pollination deficits that directly reduce crop yield and quality.


Our Solution:
- AgriPollinate is a Light Detection and Ranging (LiDAR)-powered monitoring system that continuously tracks pollinator activity and generates easy-to-read heatmaps.
- Farmers can access these heatmaps through a simple dashboard, allowing them to quickly identify under-pollinated areas, optimize hive placement, and improve crop yield and quality.

# Subsystem Overview

Power; Data (ethernet); Pollination heatmaps; Insect Classification; PCB; TiM561 LIDAR; Rasp Pi; Camera; Cloud Analytics Platform; Farmer Dashboard; Battery; Data & Power; (USB); Faircloth; Paavan Bagla; LiDAR Data; Camera Data; WiFi; Solar Panels

LiDAR Processing Subsystem -

● Process cleaned LiDAR data
● Use ML/AI to track pollinator activity
● Generate heatmaps & statistics

SBC Subsystem - Josiah

Camera Processing & UI
Subsystem - Jason Agnew

● Collect raw LiDAR data
● Detect objects in LiDAR data
● Capture images
● Transmit cleaned data & images

● Classify pollinators
● Deliver heatmaps & statistics to easily
digestible user interface

Power Subsystem - Samuel Ramos

● Supply power to physical components
● Charge Controller for the Solar Panel

# Major Project Changes

Major changes based on lessons from 403:
- Pivoted from camera first perception to LiDAR first detection due to reliability and lighting limitations observed in 403, requiring development of a machine learning model based on LiDAR scan data
- Pivoted from browser-based machine learning using TensorFlow.js to a robust Flask API integrated with YOLOv8, significantly enhancing object detection accuracy.

# Project Timeline


# Solar Power Management Circuit

Samuel Ramos

Accomplishments since 403 ~21 hrs of effort | Ongoing progress/problems and plans until the next presentation
- Redesigned PCB board - Revised both schematics with components swaps and additional components | - Simulation of new circuits - Ordering of New Board & Components - Packaging of Project (CAD, 3D printing)

# Solar Power Management Circuit


Samuel Ramos

Simulation of Step-converter, showing a mostly flat 5V out under a 3A load.

## Solar Power Management Circuit


Samuel Ramos

New Design

Old Design

# Single Board Computer Subsystem

Josiah Faircloth
Accomplishments since 403 10 hrs of effort | Ongoing progress/problems and plans until the next presentation
Made preparatory program modifications to prepare for integration - Separate TCP connections Designed and Implemented a communication data flow protocol | Testing communication flow & evaluating computational load on Pi Testing & improving algorithm, optimize parameters, and adding new filtering features to improve performance

# SBC Subsystem


Josiah Faircloth

# LiDAR Processing & Heatmaps Subsystem

Paavan Bagla
Accomplishments since 403
10 hrs of effort

Ongoing progress/problems and plans until the next presentation
- LiDAR data acquisition and logging pipeline is fully
functional from 403
- Defined a pollination focused detection approach using
persistent occupancy instead of flying insect detection
- Defining input features for ML model and baseline classifier performance
- Visualize and validate sample pollination events from real LiDAR data
- Establish reliable and validated communication from the SBC to receive LiDAR event data from the Raspberry Pi

## LiDAR Processing & Heatmaps Subsystem (403)

Paavan Bagla


## LiDAR Processing & Heatmaps Subsystem (404)


Paavan Bagla

# Camera Processing & UI Subsystem

Jason Agnew
Accomplishments since 403
15 hrs of effort

Ongoing progress/problems and plans until the next presentation

- Completed annotation of real field images in Label Studio; exported bounding box data in YOLO format ready for training.
- Set up proper conda environment on the HPRC to support YOLOv8 GPU training
- Developed and trained an initial YOLOv8 object detection model focused on identifying bees using the custom annotated dataset.
- Continue gathering additional field images, especially including other insect species, to expand training data and improve model accuracy and robustness.
- Establish a robust interface for sending insect detection results (species classification and bounding box coordinates) back to the Raspberry Pi, using the TCP protocol.
- Prepare workflow for incremental inclusion of newly collected insect species as additional object classes in YOLO annotations and training.
- Add more features to the frontend.

# Camera Processing & UI Subsystem

Jason Agnew


- box_loss: Are the bounding boxes in the right place?
- cls_loss: Prediction of correct class
- dfl_loss: Are the box edges localized sharply?

right?; find?; 50% IoU)?; across multiple levels of overlap?

- Precision: When I say I found a bee, am I
- Recall: Of all possible bees, how many did I
- mAP50: How good is the average detection (at
- mAP50-95: How well-detailed are my boxes,

# Execution Plan


# Validation Plan


# Final slide – thank your audience

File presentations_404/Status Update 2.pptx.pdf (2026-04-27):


# Team 33: SickSense Pathfinder Bi-Weekly Update 2

Jason Agnew, Josiah Faircloth, Samuel Ramos,

### Paavan Bagla Sponsor: SICK Faculty: Stavros Kalafatis TA: Roman Vengas


# Project Summary

Problem Statement:
- Farmers lack reliable, real-time insights into pollination activity. Existing methods are reactive, labor-intensive, and often inaccurate, leading to missed pollination deficits that directly reduce crop yield and quality.


Our Solution:
- AgriPollinate is a Light Detection and Ranging (LiDAR)-powered monitoring system that continuously tracks pollinator activity and generates easy-to-read heatmaps.
- Farmers can access these heatmaps through a simple dashboard, allowing them to quickly identify under-pollinated areas, optimize hive placement, and improve crop yield and quality.

# Subsystem Overview

Power; Data (ethernet); Pollination heatmaps; Insect Classification; PCB; TiM561 LIDAR; Rasp Pi; Camera; Cloud Analytics Platform; Farmer Dashboard; Battery; Data & Power; (USB); Faircloth; Paavan Bagla; LiDAR Data; Camera Data; WiFi; Solar Panels

LiDAR Processing Subsystem -

● Process cleaned LiDAR data
● Use ML/AI to track pollinator activity
● Generate heatmaps & statistics

SBC Subsystem - Josiah

Camera Processing & UI
Subsystem - Jason Agnew

● Collect raw LiDAR data
● Detect objects in LiDAR data
● Capture images
● Transmit cleaned data & images

● Classify pollinators
● Deliver heatmaps & statistics to easily
digestible user interface

Power Subsystem - Samuel Ramos

● Supply power to physical components
● Charge Controller for the Solar Panel

# Project Timeline

Subsystem
reevaluation,
redesigns and
planning

Order PCB,
basic
integration
preparation
(completed
2/5)

Basic
integration for
processing
systems &
SBC (to
complete by
2/25)

Complete
Integration
including PCB
(to complete
by 3/18)

Subsystem
optimization
& holistic
validation
(to complete
by 4/1)

Final demo
and Report
(to complete
by 4/24)

# Solar Power Management Circuit

Samuel Ramos

Accomplishments since last update 15 hrs of effort | Ongoing progress/problems and plans until the next presentation
- Finalized design of the PCB - Ordering of the PCB & Components | - Soldering of said PCB - Integration of PCB into testing - Complete design of encasing for our project

## Solar Power Management Circuit

Samuel Ramos


Very rough sketch!!

Accomplishments since last update ~14 hrs of effort

Ongoing progress/problems and plans until the next presentation

- Designed and implemented event detection logic to identify potential pollinator interactions from continuous LiDAR scans
- Completed LiDAR data logging module in preparation for ML model integration
- Complete feature extraction implementation from logged LiDAR data
- Generate labeled dataset for pollinator vs non pollinator events
- Train initial baseline ML model
- Integrate trained model into live LiDAR processing pipeline

# LiDAR Processing & Heatmaps Subsystem

Paavan Bagla

# LiDAR Processing & Heatmaps Subsystem

Paavan Bagla


# LiDAR Processing & Heatmaps Subsystem


Paavan Bagla

# CAD Models: Beetle & Honeybee

# Single Board Computer Subsystem

Josiah Faircloth

Accomplishments since last update ~15 hrs of effort | Ongoing progress/problems and plans until the next presentation
Debugged and integrated communication data flow - Finalized protocol programs - Finalized camera/UI communication - Modified main program to standardize LiDAR data formatting | Assist basic integration steps between camera & LiDAR processing systems Test & improve detection algorithm for accuracy and efficiency, optimize parameters, evaluate potential new filtering features to improve performance

# SCB Subsystem


Josiah Faircloth

# Camera Processing & UI Subsystem

Jason Agnew
Accomplishments since last update
~14 hrs of effort

Ongoing progress/problems and plans until the next presentation

- Evaluated detection model on validation data
- Built initial Python API/inference script (FastAPI) for local testing
- Implemented the new TCP protocol in the Node.js backend to receive multiple images from the Raspberry Pi, return classification results, and handle heatmap data from the LiDAR subsystem.
- Continue gathering additional field images, especially including other insect species, to expand training data and improve model accuracy and robustness.
- Fetch images from Raspberry Pi via TCP in Node.js, POST images to FastAPI for YOLOv8 detection, send detection results back to the Raspberry Pi over TCP.
- Work on formatting of heatmap in frontend using simulated heatmap

# Camera Processing & UI Subsystem


Jason Agnew

Summary metrics:

Mean precision: 0.794

Mean recall: 0.891

mAP@0.5: 0.882

mAP@0.5:0.95: 0.282

# Execution Plan


# Validation Plan


# Thank you for listening!

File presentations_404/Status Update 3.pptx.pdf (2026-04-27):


# Team 33: SickSense Pathfinder Bi-Weekly Update 3

Jason Agnew, Josiah Faircloth, Samuel Ramos,

### Paavan Bagla Sponsor: SICK Faculty: Stavros Kalafatis TA: Roman Vengas


# Project Summary

Problem Statement:
- Farmers lack reliable, real-time insights into pollination activity. Existing methods are reactive, labor-intensive, and often inaccurate, leading to missed pollination deficits that directly reduce crop yield and quality.


Our Solution:
- AgriPollinate is a Light Detection and Ranging (LiDAR)-powered monitoring system that continuously tracks pollinator activity and generates easy-to-read heatmaps.
- Farmers can access these heatmaps through a simple dashboard, allowing them to quickly identify under-pollinated areas, optimize hive placement, and improve crop yield and quality.

# Subsystem Overview

Power; Data (ethernet); Pollination heatmaps; Insect Classification; PCB; TiM561 LIDAR; Rasp Pi; Camera; Cloud Analytics Platform; Farmer Dashboard; Battery; Data & Power; (USB); Faircloth; Paavan Bagla; LiDAR Data; Camera Data; WiFi; Solar Panels

LiDAR Processing Subsystem -

● Process cleaned LiDAR data
● Use ML/AI to track pollinator activity
● Generate heatmaps & statistics

SBC Subsystem - Josiah

Camera Processing & UI
Subsystem - Jason Agnew

● Collect raw LiDAR data
● Detect objects in LiDAR data
● Capture images
● Transmit cleaned data & images

● Classify pollinators
● Deliver heatmaps & statistics to easily
digestible user interface

Power Subsystem - Samuel Ramos

● Supply power to physical components
● Charge Controller for the Solar Panel

# Project Timeline

Subsystem
reevaluation,
redesigns and
planning

Order PCB,
basic
integration
preparation
(completed
2/5)

Basic
integration for
processing
systems &
SBC (to
complete by
2/25)

Complete
Integration
including PCB
(to complete
by 3/18)

Subsystem
optimization
& holistic
validation
(to complete
by 4/1)

Final demo
and Report
(to complete
by 4/24)

# Solar Power Management Circuit

Samuel Ramos

Accomplishments since last update 20 hrs of effort | Ongoing progress/problems and plans until the next presentation
- Soldered PCB w/ original parts - Ordered new parts for PCB | - Solder new components - Test PCB with and without load - Continue working with CAD for the housing of our project

# Solar Power Management Circuit


Samuel Ramos

Housing with LiDAR and Pi5 | Soldered PCB

# Single Board Computer Subsystem

Josiah Faircloth

Accomplishments since last update 18 hrs of effort | Ongoing progress/problems and plans until the next presentation
Finalized communication validation between camera and lidar clients. Full end to end latency less than 2 seconds Slight redesign to resolve latency issues in real time LiDAR scan processing | Began optimizing algorithm for edge case performance Test & improve detection algorithm for accuracy and efficiency, optimize parameters, evaluate potential new filtering features to improve performance

# SCB Subsystem


Josiah Faircloth

# LiDAR Processing & Heatmaps Subsystem

Paavan Bagla

Accomplishments since last update
20 hrs of effort

Ongoing progress/problems and plans until the next presentation

- Completed integration between SBC and LiDAR camera
subsystem with verified real time data acquisition and logging
- Integrated visit accumulation logic with heatmap generation pipeline, including persistent visit count storage across multiple scans
- Conducted end to end functional system testing from LiDAR scan to heatmap output, confirming correct data flow, accumulation, and visualization
- Generate labeled dataset for pollinator vs non pollinator events
- Train initial baseline ML model
- Integrate trained model into live LiDAR processing pipeline

# LiDAR Processing & Heatmaps Subsystem

Paavan Bagla


# Camera Processing & UI Subsystem

Jason Agnew

Accomplishments since last update
18 hrs of effort

Ongoing progress/problems and plans until the next presentation

- Implemented a FastAPI backend server to efficiently support the YOLOv8 detection model, seamlessly integrating it with the Node.js server architecture and communication protocol
- Achieved smooth system functionality, ensuring the rapid transmission of classification results to the Raspberry Pi. The system also uploads annotated images to the frontend and retrieves the LiDAR heatmap within 1 second of image reception.
- Conduct thorough testing for multiple object detection capabilities
- Refine and enhance data collection techniques to improve dashboard visualizations, ensuring compatibility with the newly implemented backend classification method.

# Camera Processing & UI Subsystem


Jason Agnew

# Execution Plan


# Validation Plan


# Thank you for listening!

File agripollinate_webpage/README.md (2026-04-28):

# Agripollinate Web Application

This folder contains the web application for Agripollinate. It includes:
- **`farmer-dashboard/`** — React frontend
- **`farmer-dashboard-backend/`** — Express backend
- **Root package scripts** that start the frontend, backend, and ML service together

## Quick Start

From `agripollinate_webpage/`:

```bash
npm install
npm run setup
npm run dev
```

- `npm run setup` installs dependencies for the root package, frontend, backend, and ML service.
- `npm run dev` starts the complete system:
  - React frontend
  - Express backend
  - Python ML service

This is the command users should run to start the whole program.

## Project Structure

```
agripollinate_webpage/
├── farmer-dashboard/                # React frontend
│   ├── public/                      # Static files
│   ├── src/                         # React app source code
│   ├── App.jsx                      # Root application component
│   ├── main.jsx                     # Vite entry point
│   └── package.json                 # Frontend package and scripts
├── farmer-dashboard-backend/        # Express backend + ML integration
│   ├── server4.js                   # Main backend server
│   ├── batchCollector.js            # Event batch logic
│   ├── package.json                 # Backend package and scripts
│   └── ml/                          # Python ML service
│       ├── run.js                   # ML service launcher
│       ├── setup-ml.js              # ML environment helper
│       ├── ml.py                    # Python ML service entrypoint
│       └── best.pt                  # Trained ML model
├── package.json                     # Root scripts for running all services
└── README.md                        # This file
```

## Root Package Scripts

The root `package.json` coordinates the full web app:

- `npm run dev` — start frontend, backend, and ML service together
- `npm run dev:ml` — start only the ML service
- `npm run setup` — install dependencies and prepare the ML environment
- `npm run setup:ml` — create the Python virtual environment for ML
- `npm run setup:ml:install` — install ML Python dependencies

## Frontend

The frontend lives in `farmer-dashboard/`.

### Stack

- React 19.1.1
- Vite
- Tailwind CSS
- React Router 7.9
- Heroicons React
- TensorFlow.js
- @tensorflow-models/mobilenet

### Frontend Scripts

```bash
cd farmer-dashboard
npm install
npm run dev
npm run build
npm run preview
```

The development server runs by default at `http://localhost:5173`.

## Backend

The backend lives in `farmer-dashboard-backend/`.

### Stack

- Node.js
- Express.js
- CORS
- dotenv
- nodemon

### Backend Scripts

```bash
cd farmer-dashboard-backend
npm install
npm run dev
npm start
```

### Backend API Endpoints

Implemented in `server4.js`:

- `GET /images/list` — latest image pairs
- `GET /images/annotated` — latest annotated images
- `GET /images/lidar` — latest LiDAR heatmap images
- `POST /detect-image` — run detection on an image by filename
- `GET /api/batches` — list batch metadata

## ML Service

The ML service is launched from `farmer-dashboard-backend/ml/run.js`.

- Starts a Python process using the virtual environment at `farmer-dashboard-backend/ml/venv`
- Runs `ml.py`
- Uses `best.pt` for the trained model
- Default service URL: `http://localhost:5000`

## Setup and Run Guide

### Full installation

From `agripollinate_webpage/`:

```bash
npm install
npm run setup
```

### Run the complete application

From `agripollinate_webpage/`:

```bash
npm run dev
```

### Run only one part

Frontend only:
```bash
npm run dev --prefix farmer-dashboard
```

Backend only:
```bash
npm run dev --prefix farmer-dashboard-backend
```

ML service only:
```bash
npm run dev:ml
```

## Environment Variables

The backend can be configured with a `.env` file in `farmer-dashboard-backend/`.

Example:

```env
RASPBERRY_PI_HOST=10.250.76.217
RASPBERRY_PI_PORT=12345
PORT=3000
LOG_LEVEL=info
NODE_ENV=development
```

The frontend currently uses the default Vite configuration and does not require a separate `.env` file unless additional environment variables are added.

## Notes

- `npm run dev` at the root is the recommended command to run the full program.
- `npm run setup` should be run the first time to install all dependencies and initialize the ML environment.
- The backend does not require a build step; it runs directly with Node.

## Additional Documentation

- Backend README: `farmer-dashboard-backend/README.md`

## File Structures

### Frontend (`farmer-dashboard/src/`)

```
src/
├── App.jsx                    # Root component with routing
├── main.jsx                   # Application entry point
├── components/               # Reusable UI components
├── pages/                    # Page-level components
├── hooks/                    # Custom React hooks
├── state/                    # State management files
├── utils/                    # Helper utilities
├── styles/                   # CSS files and Tailwind
└── assets/                   # Images and icons
```

### Backend Configuration

Key files:
- `server4.js` - Main Express application
- `batchCollector.js` - Event aggregation logic
- `.env` - Environment configuration
- `package.json` - Dependencies and scripts

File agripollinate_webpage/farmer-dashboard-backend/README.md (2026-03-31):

## 🐍 ML Service Setup

### Prerequisites
- Python 3.8+
- pip

### Setup

1. **Navigate to the ml folder**
```bash
   cd ml
```

2. **Create a virtual environment**
```bash
   python3 -m venv venv
```

3. **Activate the virtual environment**
```bash
   # Mac/Linux
   source venv/bin/activate

   # Windows
   venv\Scripts\activate
```

4. **Install dependencies**
```bash
   pip install fastapi uvicorn ultralytics pillow torch torchvision python-multipart
```

5. **Run the ML server**
```bash
   python ml.py
```

   You should see:
```
   ✅ Model loaded successfully!
   🚀 Starting FastAPI ML Detection Service...
```

### Notes
- The server runs on `http://localhost:5000`
- To stop the environment when done: `deactivate`
- `venv/` is gitignored — each developer must set it up locally

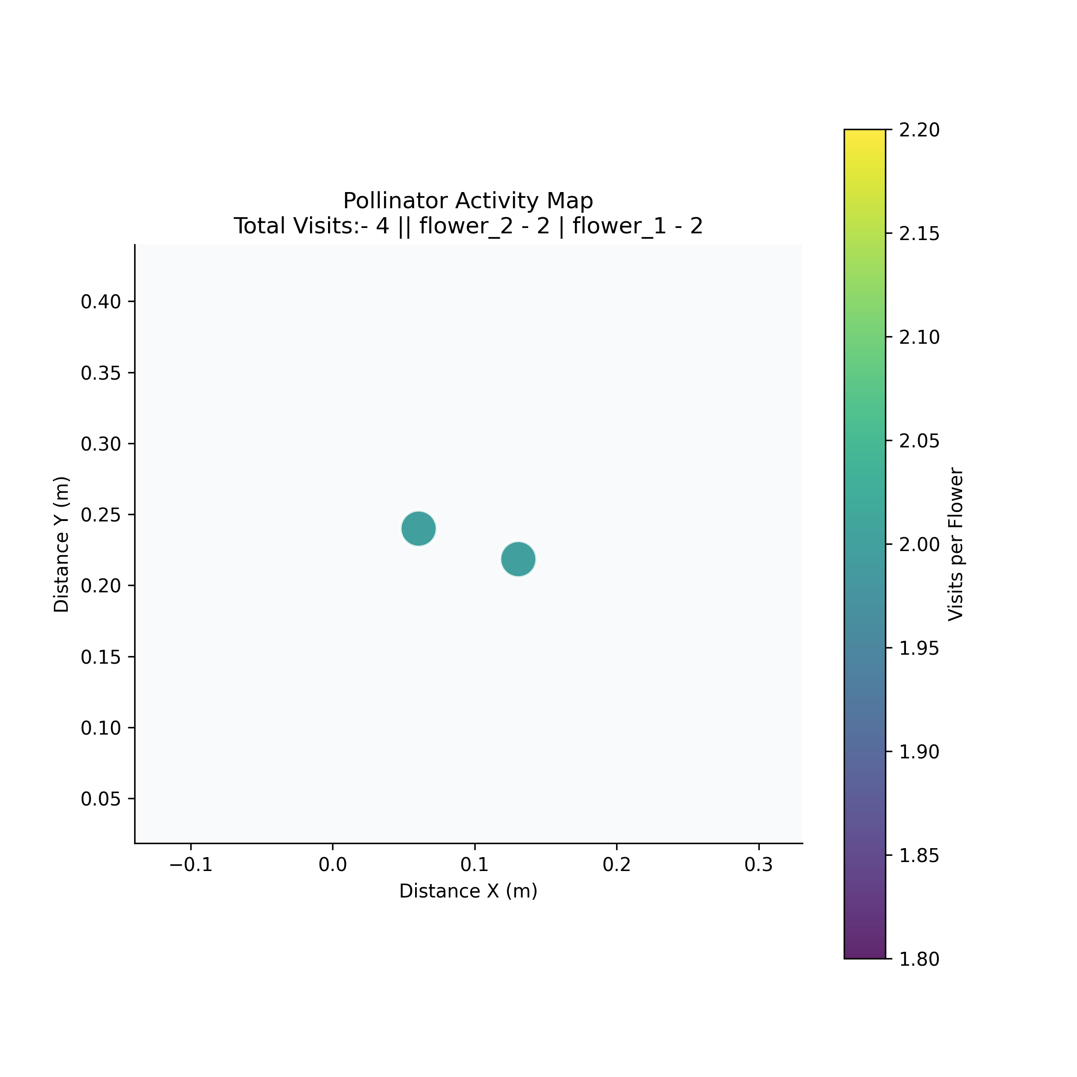
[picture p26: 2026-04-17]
lidar_client_communication/generated_heatmaps/heatmap_04-16-2026_15.21.38.977.png

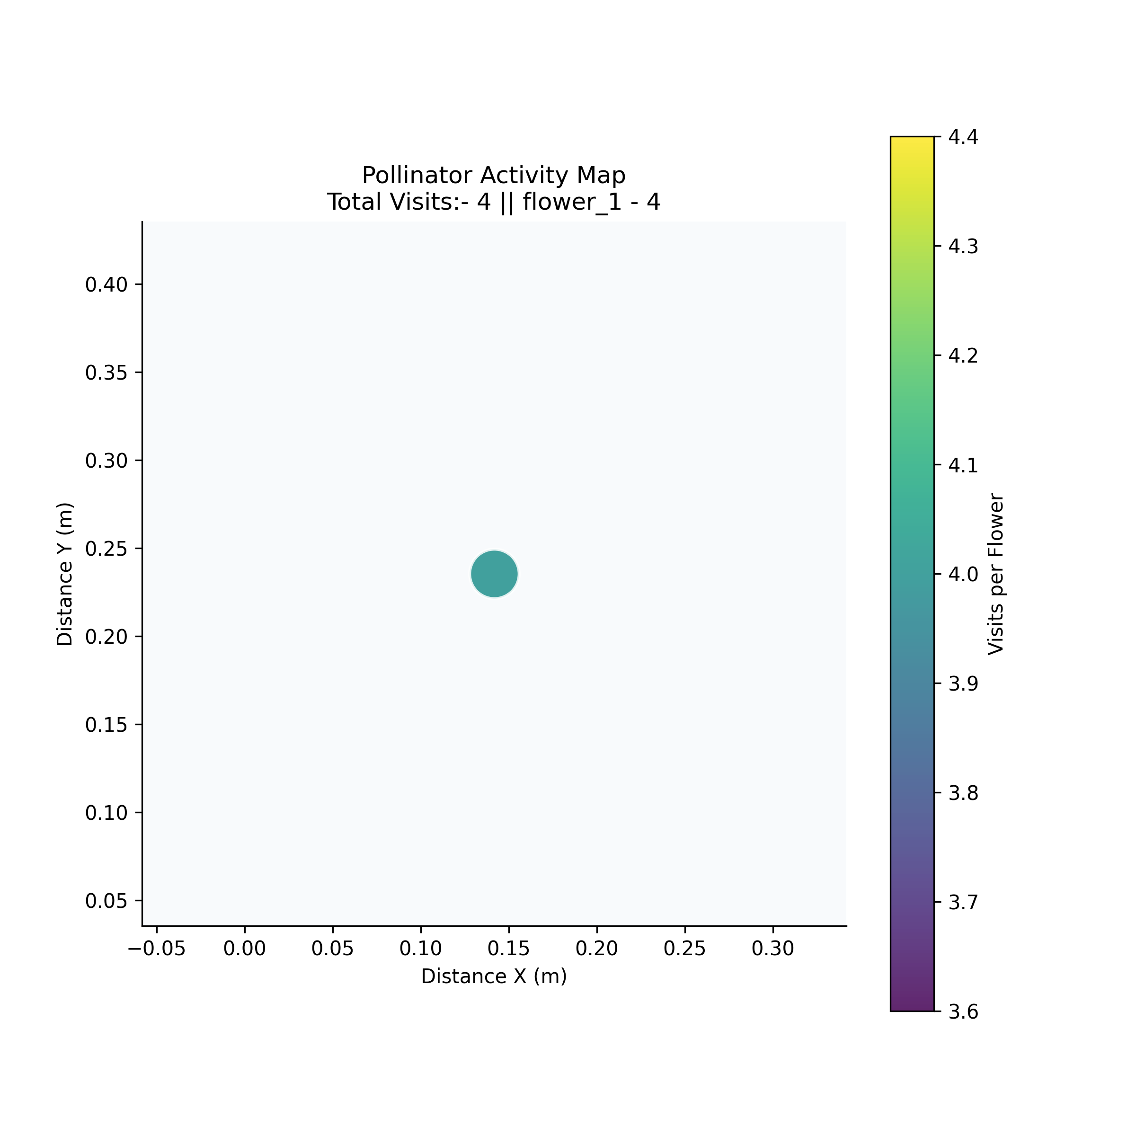
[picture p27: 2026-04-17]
lidar_client_communication/generated_heatmaps/heatmap_04-16-2026_16.46.43.184.png

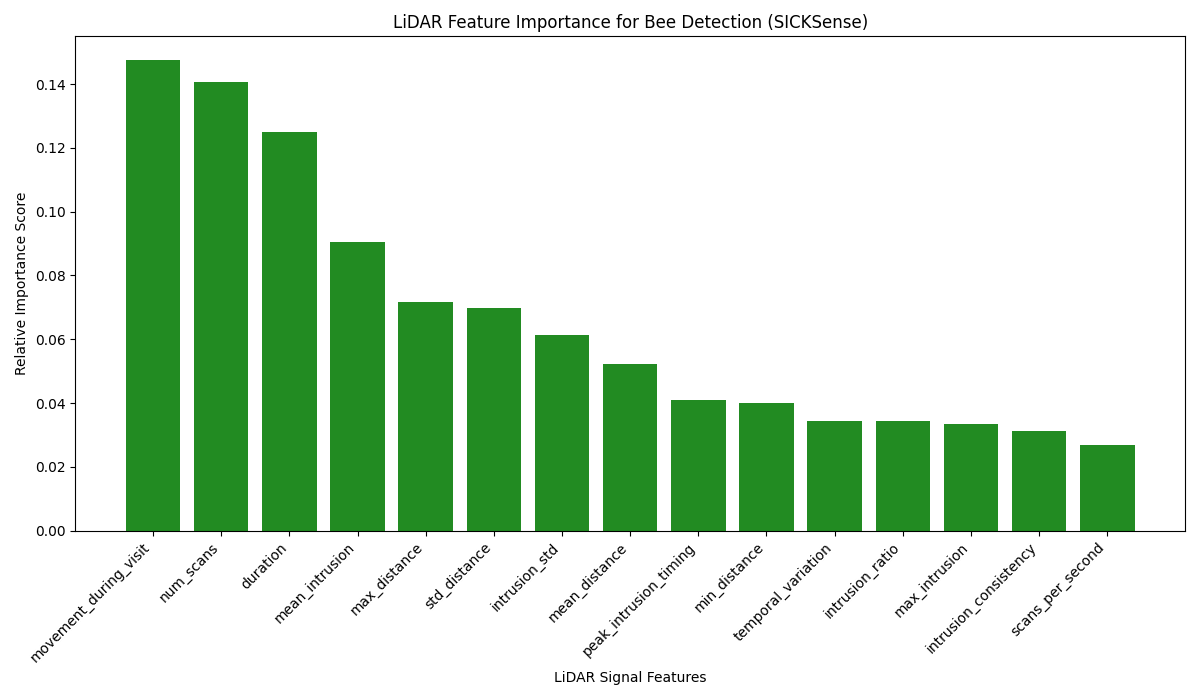
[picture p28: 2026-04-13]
lidar_ML/features/feature_importance.png

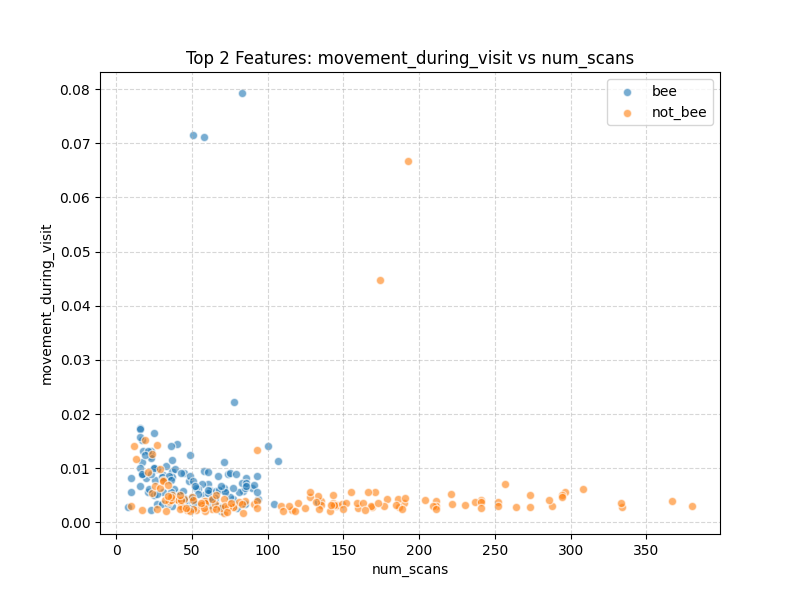
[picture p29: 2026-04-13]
lidar_ML/features/new_feature_scatter.png

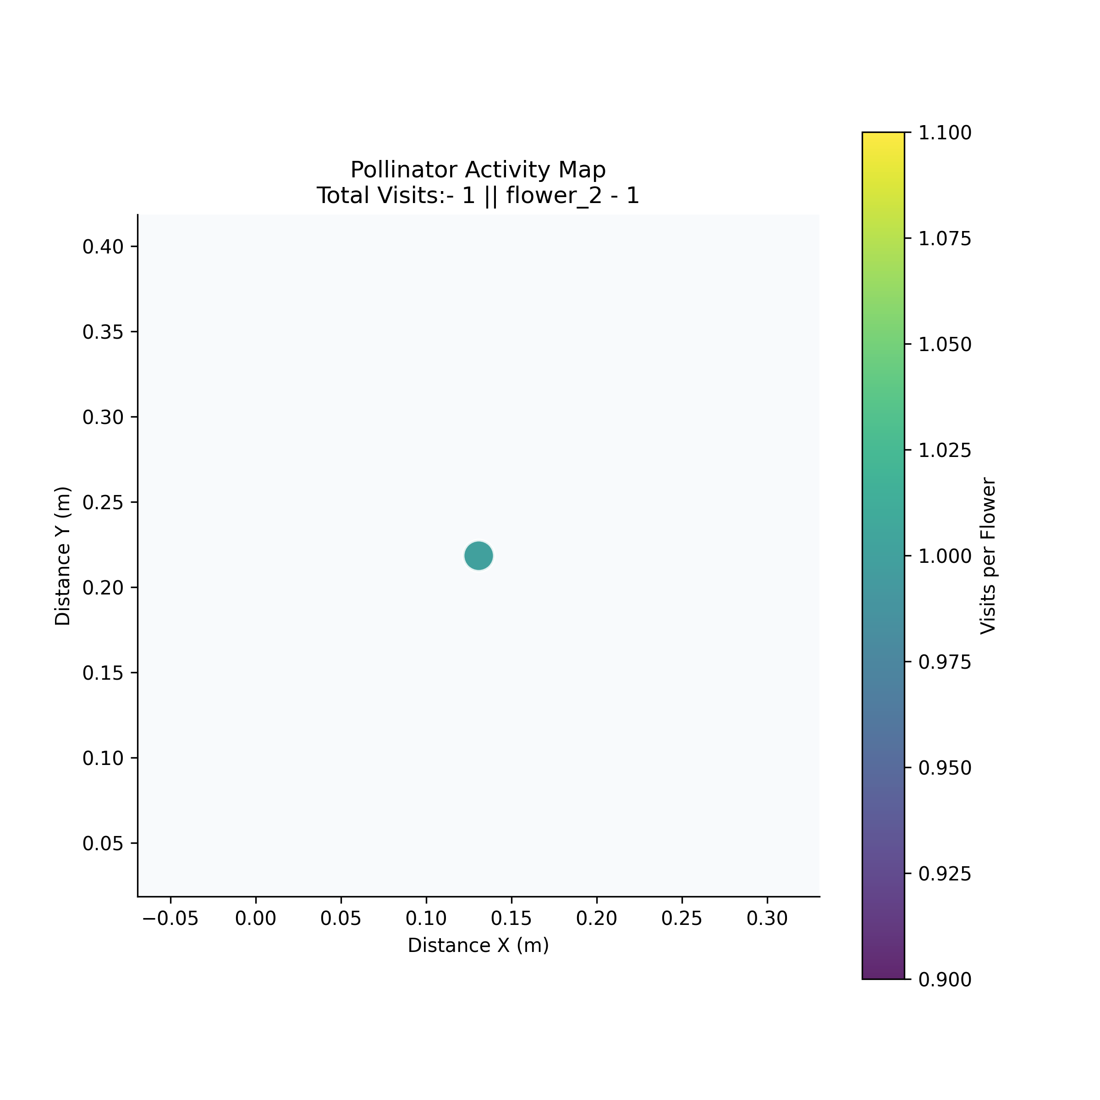
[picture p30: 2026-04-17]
lidar_client_communication/generated_heatmaps/heatmap_04-16-2026_15.14.49.331.png

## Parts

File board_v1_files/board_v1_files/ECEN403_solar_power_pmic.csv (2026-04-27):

Line # | Name | Description | Designator | Manufacturer 1 | Manufacturer Part Number 1 | Manufacturer Lifecycle 1 | Supplier 1 | Supplier Part Number 1 | Supplier Unit Price 1 | Supplier Subtotal 1 | Quantity
 | 1N5400G | Standard Recovery Rectifier, 2-Pin Axial_Lead, Pb-Free, Bulk Box | D3 | onsemi | 1N5400G | Volume Production | Arrow Electronics | 1N5400G | 0.2436 | 0.2436 | 3
 | BD242BG | Complementary Silicon Plastic Power Transistor, 3-Pin TO-220, Pb-Free, Tube | Q1 | onsemi | BD242BG | End of Life | Arrow Electronics | BD242BG | 0.2103 | 0.2103 | 3
 | CRCW0805200KJNEA |  | R_A | Vishay | CRCW0805200KJNEA | Volume Production | Arrow Electronics | CRCW0805200KJNEA | 0.0036 | 0.0036 | 3
 | LM2678T-12/NOPB | SIMPLE SWITCHER® High Efficiency 5A Step-Down Voltage Regulator, 7-pin TO-220, Pb-Free | U1 | Texas Instruments | LM2678T-12/NOPB | Volume Production | Arrow Electronics | LM2678T-12/NOPB | 0.556 | 0.556 | 3
 | 1N4001-E3/73 | DIODE GEN PURP 50V 1A DO204AL | D2 | Vishay | 1N4001-E3/73 | Volume Production | DigiKey | 1N4001-E3/73GICT-ND | 0.15 | 0.15 | 3
 | 6.94108E+11 |  | J3 | Wurth Elektronik | 6.94108E+11 | Unknown | DigiKey | 732-5934-ND | 0.92 | 0.92 | 3
 | BQ24450DWTR | Integrated Charge Controller for Lead-Acid Batteries, 5 V, 16-pin SOIC (DW), Green (RoHS & no Sb/Br) | U2 | Texas Instruments | BQ24450DWTR | Volume Production | DigiKey | 296-24367-1-ND | 9.71 | 9.71 | 3
 | C2012C0G1H103K060AA | Multilayer Ceramic Capacitors 10nF ±10% 50V C0G SMD 0805 | C3 | TDK | C2012C0G1H103K060AA | Not Recommended for New Design | DigiKey | 445-14311-1-ND | 0.27 | 0.27 | 3
 | CB2518T100K | SMD Inductors 10uH ±10% 0.82A 0.325O 1007 | L1 | Taiyo Yuden | CB2518T100K | Volume Production | DigiKey | 587-2189-1-ND | 0.12 | 0.12 | 3
 | CRCW080513K0JNEA | RES Thick Film, 13kO, 5%, 0.125W, 200ppm/°C, 0805 | R_P | Vishay | CRCW080513K0JNEA | Volume Production | DigiKey | 541-13KACT-ND | 0.1 | 0.1 | 3
 | GRM155R71C104KA88D | CAP CER 0.1UF 16V X7R 0402 | C2 | Murata | GRM155R71C104KA88D | Not Recommended for New Design | DigiKey | 490-3261-1-ND | 0.1 | 0.1 | 3
 | RG3216P-1503-B-T5 | Automotive Metal Thin Film Chip Resistor, 1206, 150kO, 0.1%, 25ppm/°C, 0.25W, 200V | R_D2 | Susumu | RG3216P-1503-B-T5 | Volume Production | DigiKey | 408-RG3216P-1503-B-T5CT-ND | 0.23 | 0.23 | 3
 | RT0603BRC07500RL | Fixed Resistor, Thin Film, 0.1W, 500ohm, 75V, 0.1% +/-Tol, 15ppm/Cel, Surface Mount, 0603 | R_comp | Yageo Group | RT0603BRC07500RL | Volume Production | DigiKey | 13-RT0603BRC07500RLCT-ND | 0.45 | 0.45 | 3
 | BD241CG | Complementary Silicon Plastic Power Transistor, 3-Pin TO-220, Pb-Free, Tube | Q2 | onsemi | BD241CG | Volume Production | Farnell | 3253662 | 1.35 | 1.35 | 3
 | ECA1HHG331B | Aluminum Electrolytic Capacitors (Radial Lead Type) AEC-Q200 Qualified 330uF ±20% 50V | Cout | Panasonic | ECA1HHG331B | Volume Production | Farnell | 3346418 | 0.72873 | 0.72873 | 3
 | RC0402FR-0746K4L |  | R_C | Yageo Group | RC0402FR-0746K4L | Volume Production | Farnell | 4013201 | 0.00763 | 0.07629 | 3
 | 282836-2 | Female Header, Pitch 5 mm, 1 x 2 Position, Height 10 mm, Tail Length 3.5 mm, Rohs, Bulk | J2 | TE Connectivity | 282836-2 | Volume Production | Future Electronics | 4188728 | 0.25 | 0.25 | 3
 | 20SVPF180M | Conductive Polymer Aluminum Solid Capacitors (OS-CON) 180uF ±20% 20V RADIAL SMT 8x6.9mm | C1 | Panasonic | 20SVPF180M | Volume Production | Mouser | 667-20SVPF180M | 1.3 | 1.3 | 3
 | 1440067 | CONN RCPT FMALE 5POS GOLD SOLDER | J4 | Phoenix Contact | 1440067 | Volume Production | Mouser | 651-1440067 | 21.27 | 21.27 | 3
 | CDBC540-G | DIODE SCHOTTKY 40V 5A DO214AB | D1 | Comchip | CDBC540-G | Obsolete | Mouser | 750-CDBC540-G | 0.66 | 0.66 | 3
 | CRMA1206AF500KFKEF | CRMA1206AF500KFKEF Res Thick Film 1206 500K Ohm 1% 0.3W ±100ppm/C Pad SMD Automotive T/R | R_D1 | Vishay | CRMA1206AF500KFKEF | Volume Production | Mouser | 71-CRMA1206AF500KFKF | 0.41 | 0.41 | 3
 | ERJ-2GEJ681X |  | R_T | Panasonic | ERJ-2GEJ681X | Volume Production | Mouser | 667-ERJ-2GEJ681X | 0.1 | 0.1 | 3
 | RC1206FR-103K3L |  | R_B | Yageo Group | RC1206FR-103K3L | Volume Production | Mouser | 603-RC1206FR-103K3L | 0.1 | 0.1 | 3
 | USB4105-GF-A | CONN RCPT USB2.0 TYPEC 5A | J1 | Global Connector Technology | USB4105-GF-A | Volume Production | Mouser | 640-USB4105-GF-A | 0.78 | 0.78 | 3
 | WSL2512R1250FEA | Res Metal Strip 2512 0.125 Ohm 1% 1W ±75ppm/°C Molded SMD SMD Embossed Plastic T/R | R_ISNS | Vishay | WSL2512R1250FEA | Volume Production | Mouser | 71-WSL2512R1250FEA | 1.27 | 1.27 | 3
 | 08051C224K4T2A | Automotive Ceramic Capacitor, 0805, 220nF, 10%, X7R, 15%, 100V | C_comp | KYOCERA AVX | 08051C224K4T2A | Volume Production | Newark | 08AK4872 | 0.073 | 0.073 | 3
 | CRCW06035K10JNEA | RES Thick Film, 5.1kO, 5%, 0.1W, 200ppm/°C, 0603 | R1 | Vishay | CRCW06035K10JNEA | Volume Production | Newark | 89M6773 | 0.003 | 0.006 | 3
 | CRCW06035K10JNEA | RES Thick Film, 5.1kO, 5%, 0.1W, 200ppm/°C, 0603 | R2 | Vishay | CRCW06035K10JNEA | Volume Production | Newark | 89M6773 | 0.003 | 0.006 | 3

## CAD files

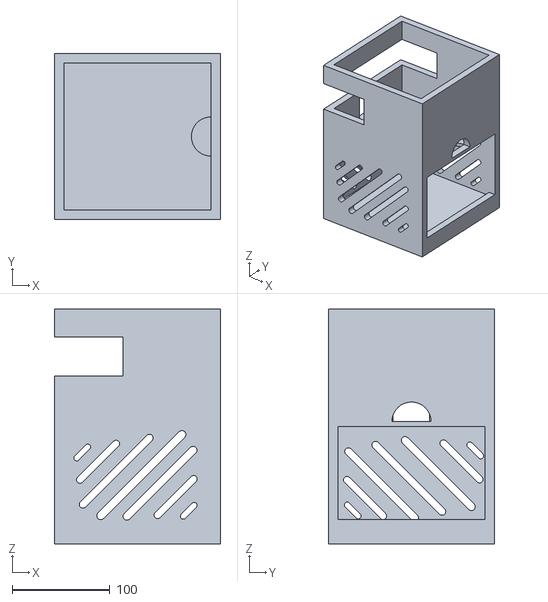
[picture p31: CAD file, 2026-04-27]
enclosing_v1_stl/enclosing_v1_stl/main_body.STL
170.0 x 170.0 x 240.0

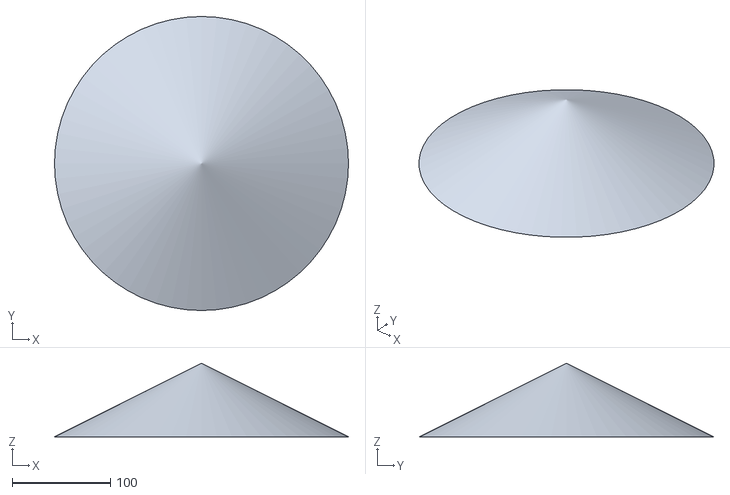
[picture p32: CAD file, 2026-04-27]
enclosing_v1_stl/enclosing_v1_stl/hat.STL
300.0 x 300.0 x 75.0

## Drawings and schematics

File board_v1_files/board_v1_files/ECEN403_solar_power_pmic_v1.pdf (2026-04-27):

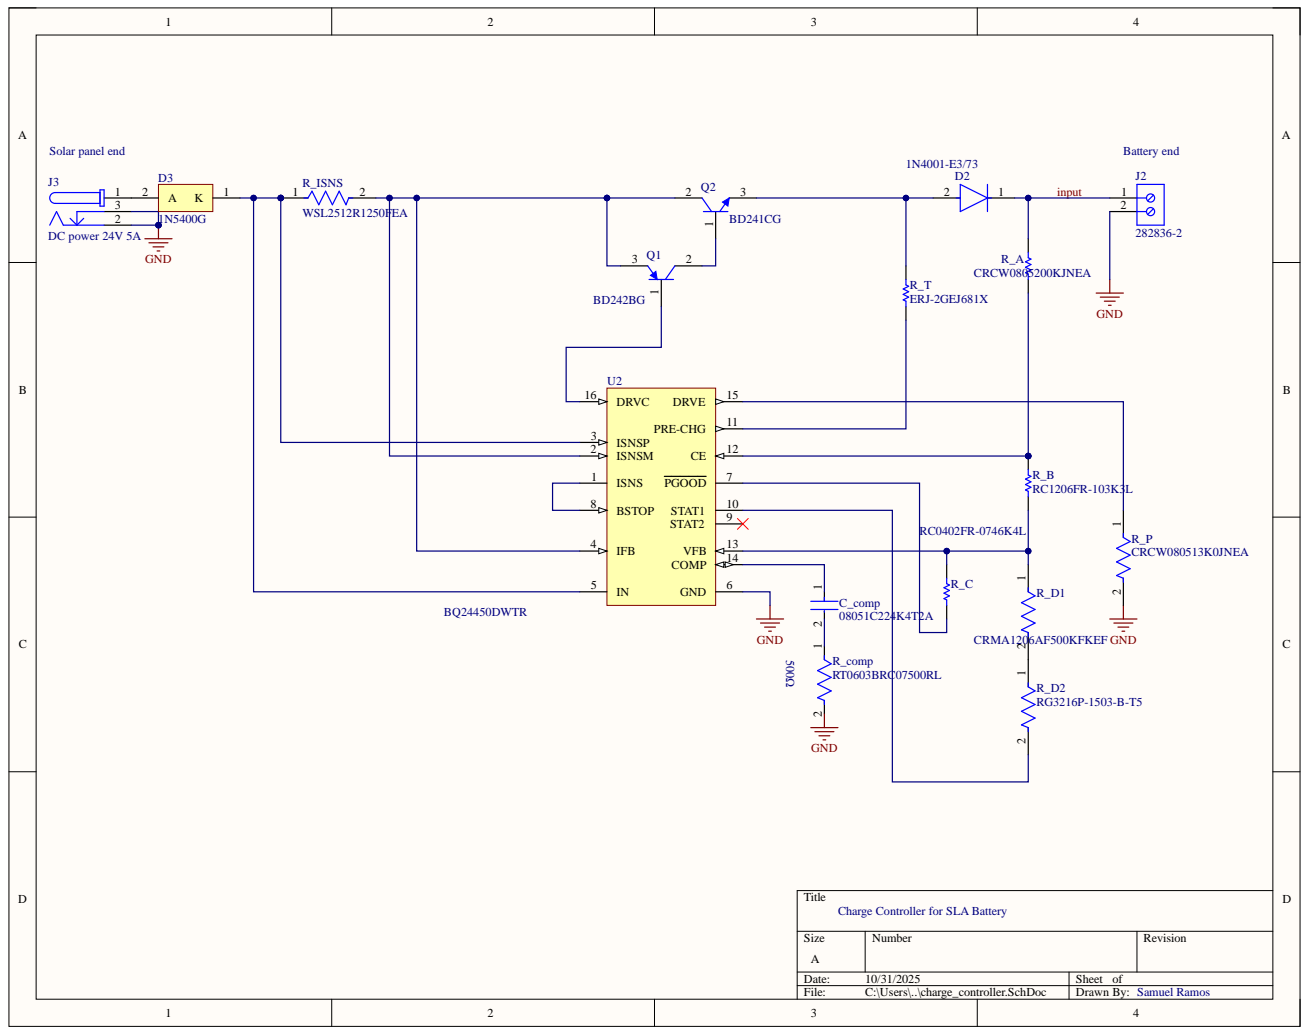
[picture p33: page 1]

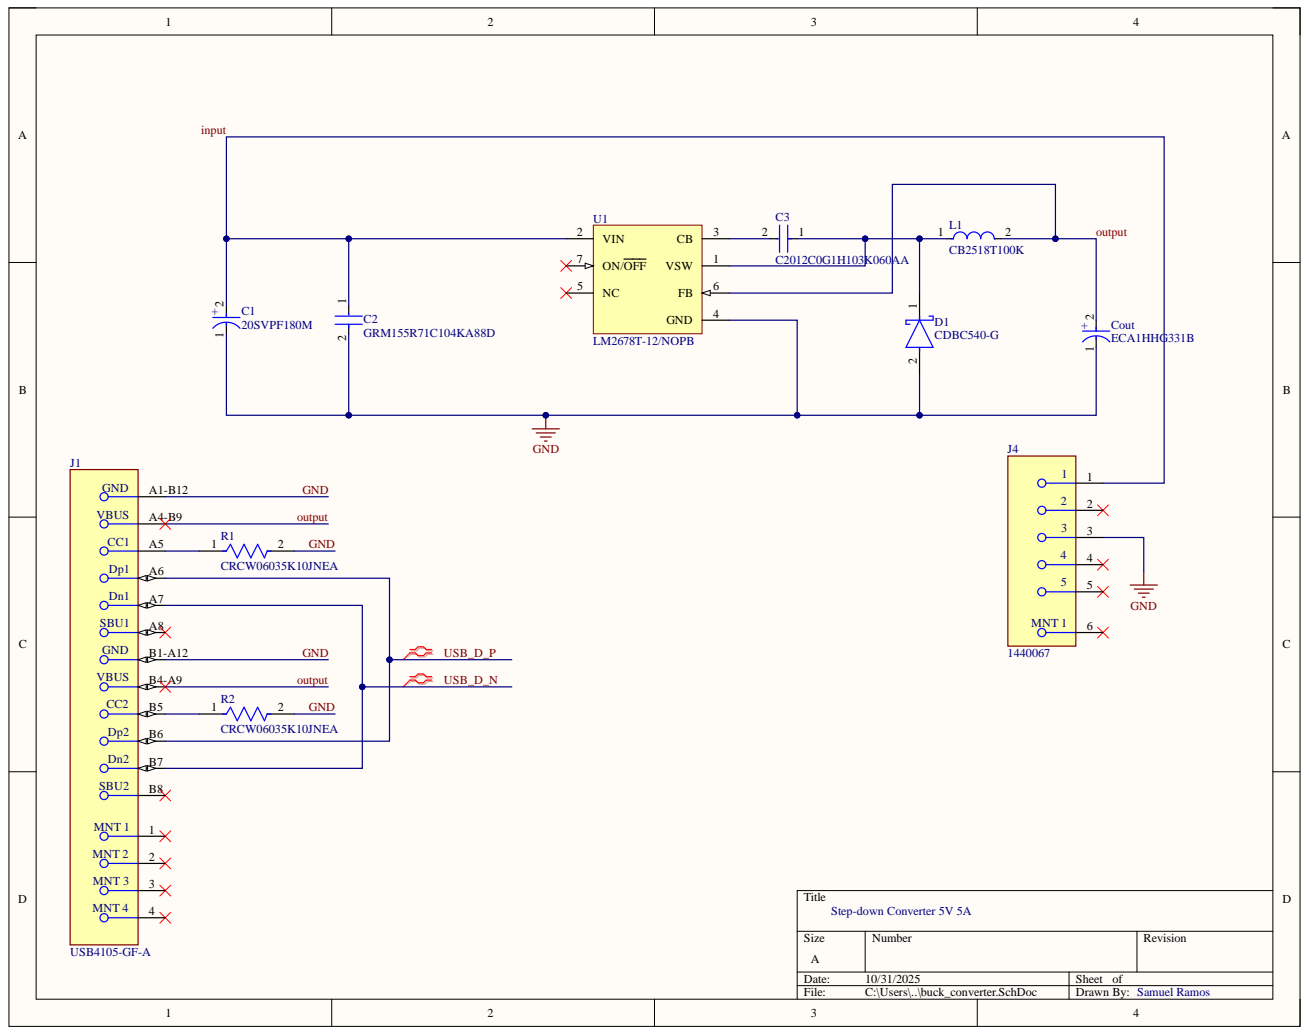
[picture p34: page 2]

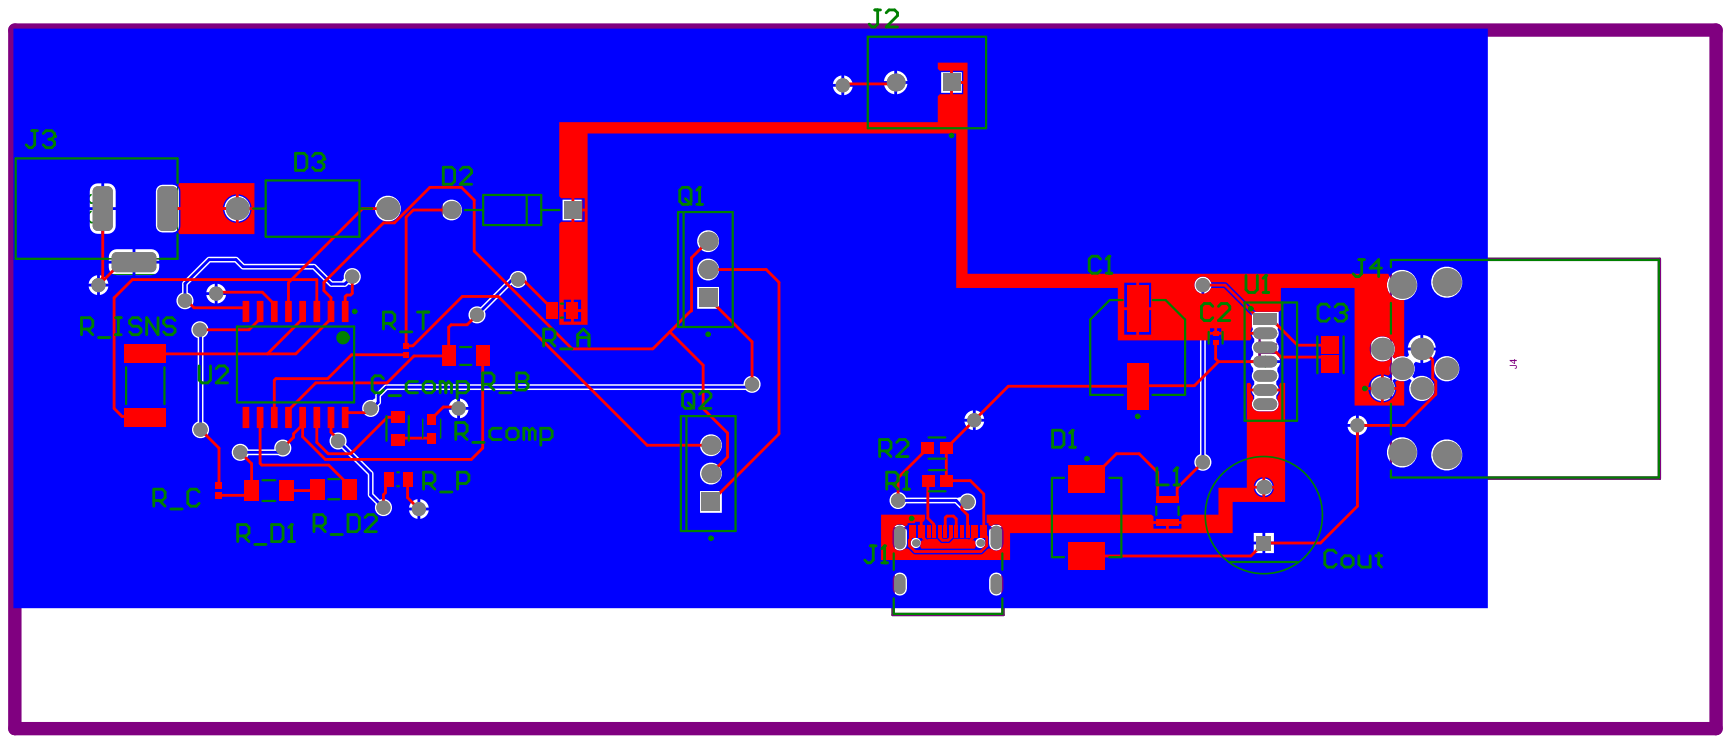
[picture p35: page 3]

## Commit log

2026-03-26 Completed the Camera-lIDAR INTEGRATION
2026-04-01 Flower and Event detection updates
2026-04-04 Added new machine learning model and handler for LiDAR subsystem .json
2026-04-06 Flower setup integrated into master_main
2026-04-13 chicken extension cable
2026-04-16 Cleaned up frontend, added batch collection logic, added filtering of classifications for frontend
